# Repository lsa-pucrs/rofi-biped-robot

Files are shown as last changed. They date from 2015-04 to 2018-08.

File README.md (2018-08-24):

# rofi-biped-robot
Unoficial repository to Rofi biped robot (http://www.projectbiped.com/prototypes/rofi)

<p align="center">
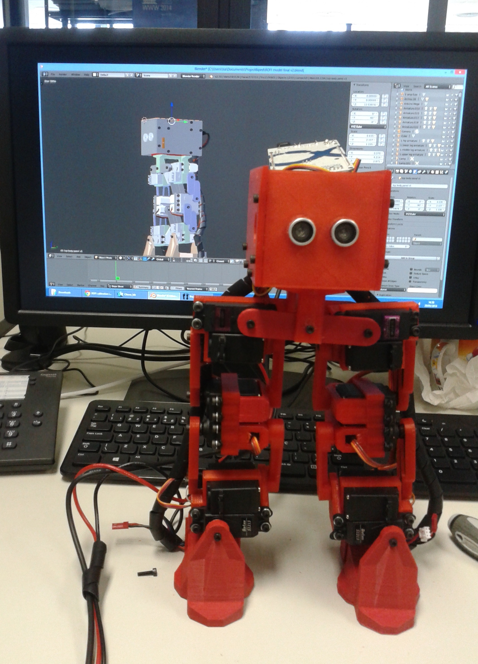
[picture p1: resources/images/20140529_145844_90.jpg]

</P>

####TO-DO_List:####
- [ ] Criar "abraçadeiras" para os servos, para melhorar a estrutura das pernas
- [ ] Manual de ultilização

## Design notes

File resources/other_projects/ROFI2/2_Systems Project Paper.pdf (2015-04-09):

1 | P a g e

# Android Controlled Based Interface

### Objective

- Fix Foba
- Build Rofi (Fifth Generation Robot)
- Develop, Build, and Implement a Dynamic Balanced Biped Robot

### Table of Contents

### Android Controlled Based Interface Design

### Embedded Systems

Engineers design systems. A system can be characterized by a box with an input and
output. Typically the engineer is tasked to design the box with a given set of inputs and a desired output.
- When a controller “the brain” is part of the design solution, the design is known as an Embedded System.
- The controller may be implemented using an ASIC (Application Integrated Circuit), FPGA (Field Programmable Gate Array) or in most cases a Microcontroller.
- For a microcontroller based design, the input device is by definition a Sensor, while the output device is known as an Actuator.
In this document we look at the Android based system design used by our rovers. It is hoped that by looking at this specific example you will be able to apply the lessons learned to the design of the Andriod based systems.

### Biped Android Based System Design

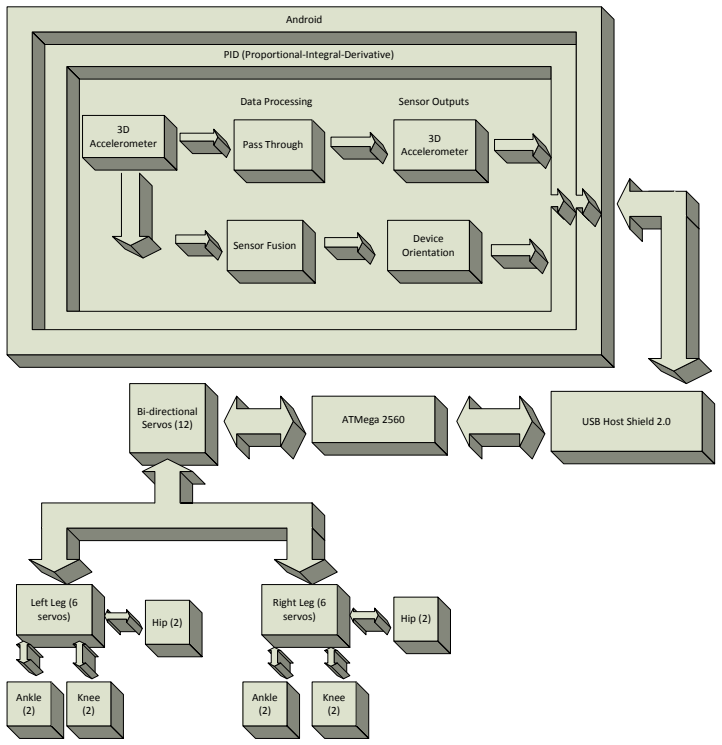
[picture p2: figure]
Sensor Fusion; 3D Accelerometer; Device Orientation; Pass Through; Android; Hip (2); Knee; (2) Ankle (2)

Data Processing | Sensor Outputs PID (Proportional-Integral-Derivative) 3D Accelerometer
ATMega 2560 | USB Host Shield 2.0 Bi-directional Servos (12)
Left Leg (6 servos) | Right Leg (6 servos) Ankle (2) | Knee

Figure 1.1 Biped Android Based System

The figure above illustrates our biped robot design from a generic capabilities perspective. At the heart of our Android we have the Android Sensor Manager.

### The ATMega2560 is built into an Arduino motherboard

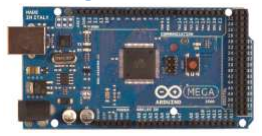
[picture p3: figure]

The Arduino Mega 2560 is a microcontroller board based on the ATmega2560 (datasheet). It has 54 digital input/output pins (of which 14 can be used as PWM outputs), 16 analog inputs, 4 UARTs (hardware serial ports), a 16 MHz crystal oscillator, a USB connection, a power jack, an ICSP header, and a reset button. It contains everything needed to support the microcontroller; simply connect it to a computer with a USB cable or power it with a AC-to-DC adapter or battery to get started. The Mega is compatible with most shields designed for the Arduino Duemilanove or Diecimila.

Important Characteristics
- Microcontroller ATmega2560
- Operating Voltage 5V
- Input Voltage (recommended) 7-12V
- Input Voltage (limits) 6-20V
- Digital I/O Pins 54 (of which 14 provide PWM output)
- Analog Input Pins 16
- DC Current per I/O Pin 40 mA
- DC Current for 3.3V Pin 50 mA
- Flash Memory 256 KB of which 8 KB used by bootloader
- SRAM 8 KB
- EEPROM 4 KB
- Clock Speed 16 MHz

### USB Host Shield 2.0 for Arduino

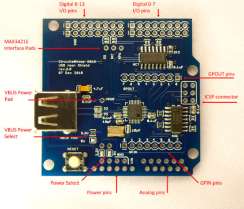
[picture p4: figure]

The figure above shows the USB Host Shield 2.0 for the Arduino. This host shield is compatible with a greater range of Arduinos, such as the Arduino UNO, Arduino Duemilanove, the big Mega and Mega 2560. SPI re-wiring and code modifications are not necessary, all you do is just solder included stackable connectors (2×3 ICSP connector’s female side should be facing down). This shield will work with standard (dual 5/3.3V) and 3.3V-only (for example, Arduino Pro) boards. Arduino clones with standard connector layout, including ICSP connector, should work, however only BlackWidow has been tested so far.

Devices that support the shield
- HID devices, such as keyboards, mice, joysticks, etc.
- USB to serial converters – FTDI, PL-2303, ACM, as well as certain cell phones and GPS receivers
- ADK-capable Android phones and tables
- Digital cameras – Canon EOS, Powershot, Nikon DSLRs and P&S, as well as generic PTP

### Interface Capabilities of our Integrated System

### Analog

Arduino | ATMega2560 | To Call Pin

USB Host
Shield | Servos

IR
Sensors
PIN 0 | PIN 97 | PF0 (ADC0)
PIN 1 | PIN 96 | PF1 (ADC1)
PIN 2 | PIN 95 | PF2 (ADC2)
PIN 3 | PIN 94 | PF3 (ADC3)
PIN 4 | PIN 93 | PF4 (ADC4/TCK)
PIN 5 | PIN 92 | PF5 (ADC5/TMS) | | Data Signal
PIN 6 | PIN 91 | PF6 (ADC6/TD0)
PIN 7 | PIN 90 | PF7 (ADC7/TDI)
PIN 8 | PIN 89 | PK0 (ADC8/PCINT16)
PIN 9 | PIN 88 | PK1 (ADC9/PCINT17) | INT

PIN 10 | PIN 87 | PK2 (ADC10/PCINT18) | SS
PIN 11 | PIN 86 | PK3 (ADC11/PCINT19)
PIN 12 | PIN 85 | PK4 (ADC12/PCINT20)
PIN 13 | PIN 84 | PK5 (ADC13/PCINT21)
PIN 14 | PIN 83 | PK6 (ADC14/PCINT22)
PIN 15 | PIN 82 | PK7 (ADC15/PCINT23)

### Digital

Arduino ATMega2560 To Call Pin

USB Host
Shield | Servos

IR
Sensors
PIN 13 | PIN 26 | PB7 (OC0A/OC1C/PCINT7)
PIN 12 | PIN 25 | PB6 (OC1B/PCINT6)
PIN 11 | PIN 24 | PB5 (OC1A/PCINT5)
PIN 10 | PIN 23 | PB4 (OC2A/PCINT4)
PIN 9 | PIN 18 | PH6 (OC2B)
PIN 8 | PIN 17 | PH5 (OC4C)
PIN 7 | PIN 16 | PH4 (OC4B)
PIN 6 | PIN 15 | PH3 (OC4A)
PIN 5 | PIN 5 | PE3 (OC3A/AIN1)
PIN 4 | PIN 1 | PG5 (OC0B)
PIN 3 | PIN 7 | PE5 (OC3C/INT5)
PIN 2 | PIN 6 | PE4 (OC3B/INT4)

### Communications

Arduino | ATMega2560 | To Call Pin | USB Host Shield | Servos

IR
Sensors
PIN 1 | PIN 3 | PE1 (TXD0)
PIN 0 | PIN 2 | PE0 (RXD0/PCINT8)
PIN 14 | PIN 64 | PJ1 (TXD3/PCINT10)
PIN 15 | PIN 63 | PJ0 (RXD3/PCINT9)
PIN 16 | PIN 13 | PH1 (TXD2)
PIN 17 | PIN 12 | PH0 (RXD2)
PIN 18 | PIN 46 | PDE (TXD1/INT3)
PIN 19 | PIN 45 | PD2 (RXD1/INT2)
PIN 20 | PIN 44 | PD1 (SDA/INT1)
PIN 21 | PIN 43 | PD0 (SCL/INT0)

### Digital

Digital
Arduino | ATMega2560 | To Call Pin | USB Host Shield | Servos | IR sensors
PIN 22 | PIN 78 | PA0 (AD0) | | Control Signal (Ankle)
PIN 23 | PIN 77 | PA1 (AD1)
PIN 24 | PIN 76 | PA2 (AD2) | | Control Signal (Lower Leg)
PIN 25 | PIN 75 | PA3 (AD3)
PIN 26 | PIN 74 | PA4 (AD4) | | Control Signal (Knee)
PIN 27 | PIN 73 | PA5 (AD5)
PIN 28 | PIN 72 | PA6 (AD6) | | Control Signal (Middle Leg)
PIN 29 | PIN 71 | PA7 (AD7)
PIN 30 | PIN 60 | PC7 (A15) | | Control Signal (Upper Leg)
PIN 31 | PIN 59 | PC6 (A14)
PIN 32 | PIN 58 | PC5 (A13) | | Control Signal (Hip)
PIN 33 | PIN 57 | PC4 (A12)
PIN 34 | PIN 56 | PC3 (A11)
PIN 35 | PIN 55 | PC2 (A10)
PIN 36 | PIN 54 | PC1 (A9)
PIN 37 | PIN 53 | PC0 (A8)
PIN 38 | PIN 50 | PD7 (T0)
PIN 39 | PIN 70 | PG2 (ALE)
PIN 40 | PIN 52 | PG1 (/RD) | | Control Signal (Ankle)
PIN 41 | PIN 51 | PG0 (/WR)
PIN 42 | PIN 42 | PL7 | | Control Signal (Lower Leg)
PIN 43 | PIN 41 | PL6
PIN 44 | PIN 40 | PL5 (OC5C) | | Control Signal (Knee)
PIN 45 | PIN 39 | PL4 (OC5B)
PIN 46 | PIN 38 | PL3 (OC5A) | | Control Signal (Middle Leg)
PIN 47 | PIN 37 | PL2 (T5)
PIN 48 | PIN 36 | PL1 (ICP5) | | Control Signal (Upper Leg)
PIN 49 | PIN 35 | PL0 (ICP4)
PIN 50 | PIN 22 | PB3 (MISO/PCINT3) | Connected via ICSP (MISO) | Control Signal (Hip)
PIN 51 | PIN 21 | PB2 (MOSI/PCINT2) | Connected via ICSP (MOSI)
PIN 52 | PIN 20 | PB1 (SCK/PCINT1) | Connected via ICSP (SCK)
PIN 53 | PIN 19 | PB0 (/SS/PCINT0)
GND | | | GND | GND | GND
AREF
5V PIN | | | PWR | PWR | PWR
RESET | | | RST

### ATmega2560 Pin Configuration(TQFP –pinout)

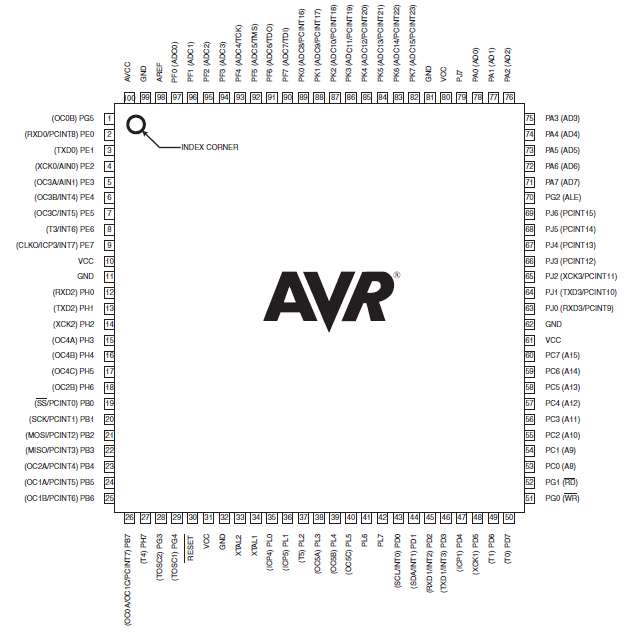
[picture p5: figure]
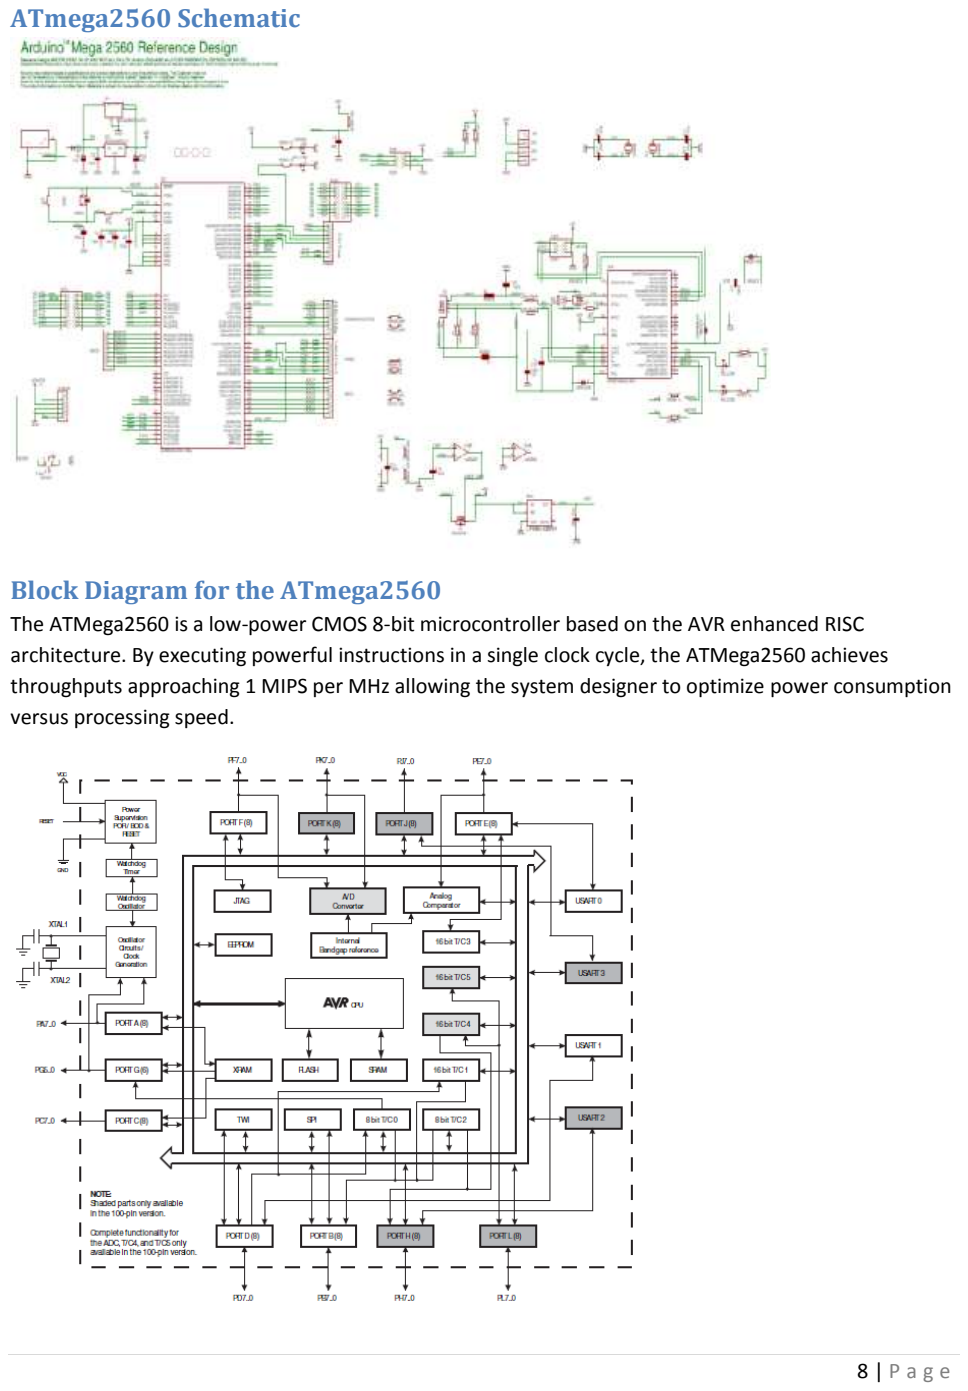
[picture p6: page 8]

### ATmega2560 Schematic

### Block Diagram for the ATmega2560

The ATMega2560 is a low-power CMOS 8-bit microcontroller based on the AVR enhanced RISC architecture. By executing powerful instructions in a single clock cycle, the ATMega2560 achieves throughputs approaching 1 MIPS per MHz allowing the system designer to optimize power consumption versus processing speed.

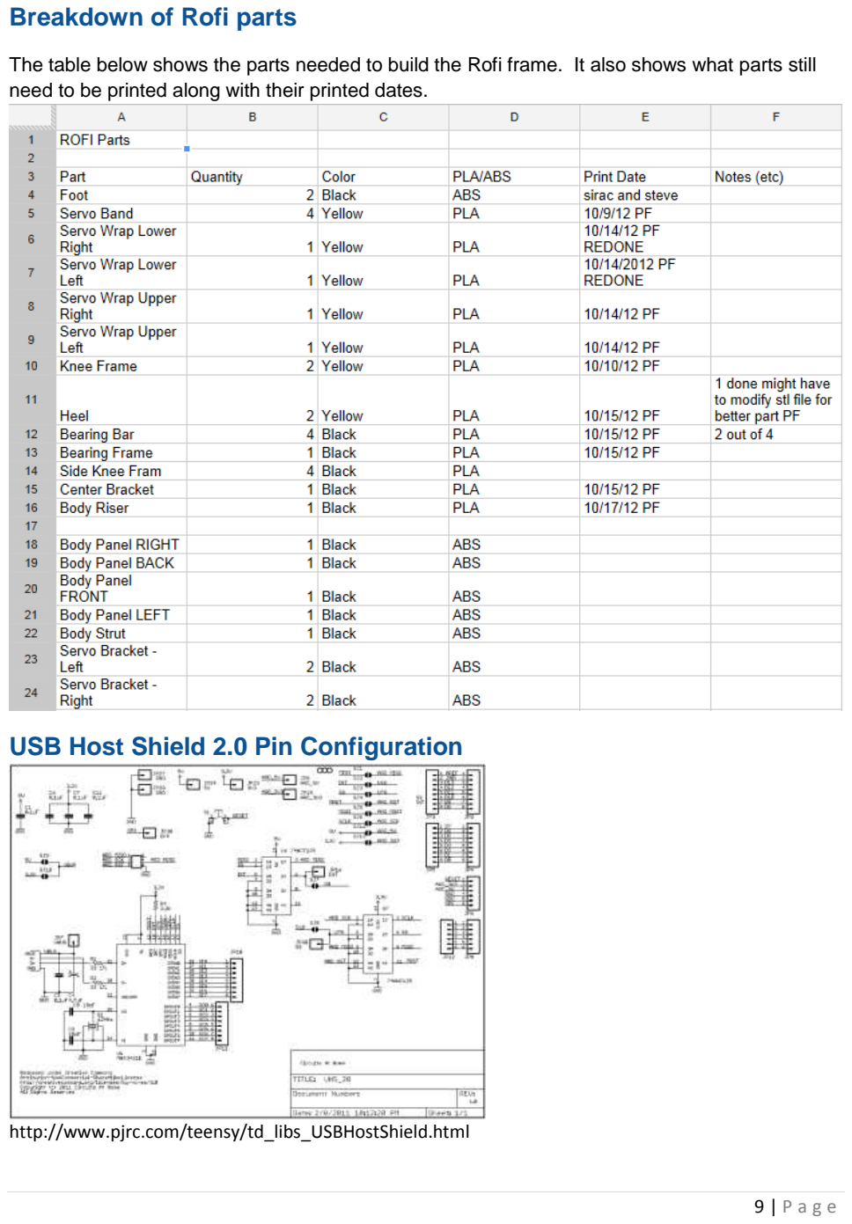
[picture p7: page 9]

### Breakdown of Rofi parts

The table below shows the parts needed to build the Rofi frame. It also shows what parts still need to be printed along with their printed dates.

### USB Host Shield 2.0 Pin Configuration

http://www.pjrc.com/teensy/td_libs_USBHostShield.html

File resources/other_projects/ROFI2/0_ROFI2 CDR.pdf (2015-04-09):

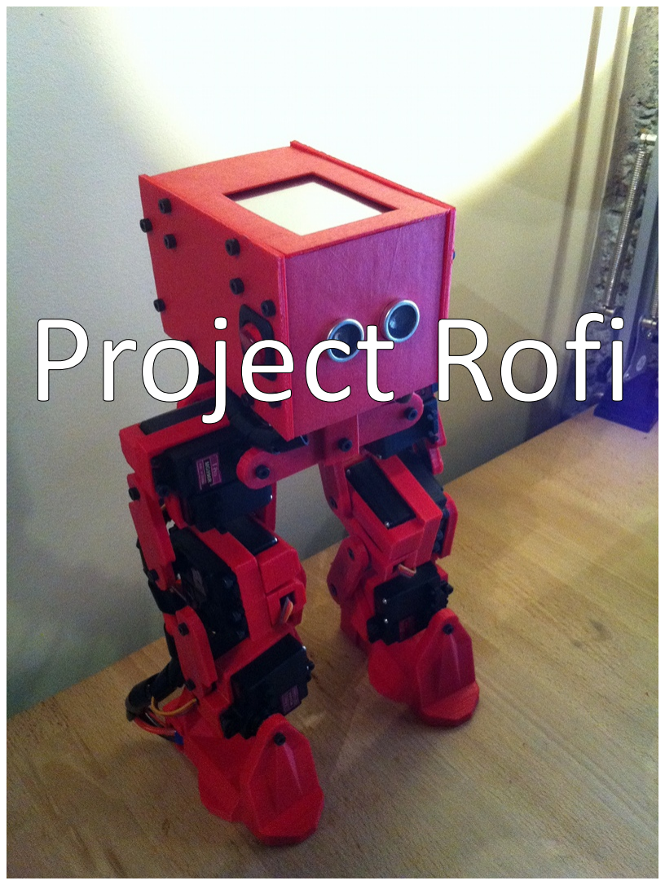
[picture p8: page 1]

### Research

- Project Biped by Jonathan Dowdall
– Fobo and Foba : static balanced
– Rofi: static but with accelerometer feedback to smooth walking
– http://www.projectbiped.com

## Rofi vs Fobo

| FoBo | Rofi
Static/Dynamic | Static | Partially Dynamic
FeedBack | None | Accelerometer
“Brain” | Arduino Uno | Android
Degrees of Freedom | 8 | 12
Sensors | Ultrasonic Range | Ultrasonic Range, Accelerometer (Android)
Batteries | 1 at center | 2, one at each foot
Plastic | 193cc, 206g (about 1/5 spool) | ABS plastic 1.75mm, 1kg
Build Time | 18 hours: 16 hours printing + 2 hours assembly | 30 hours: 25 hours printing + 5 hours assembly
Size | 9.5cm x 15.25cm x 24cm (4.5” x 6” x 9.5”) | 17.75cm x 11.45cm x 30.5cm (7” x 4.5” x 12”)

## RoFi

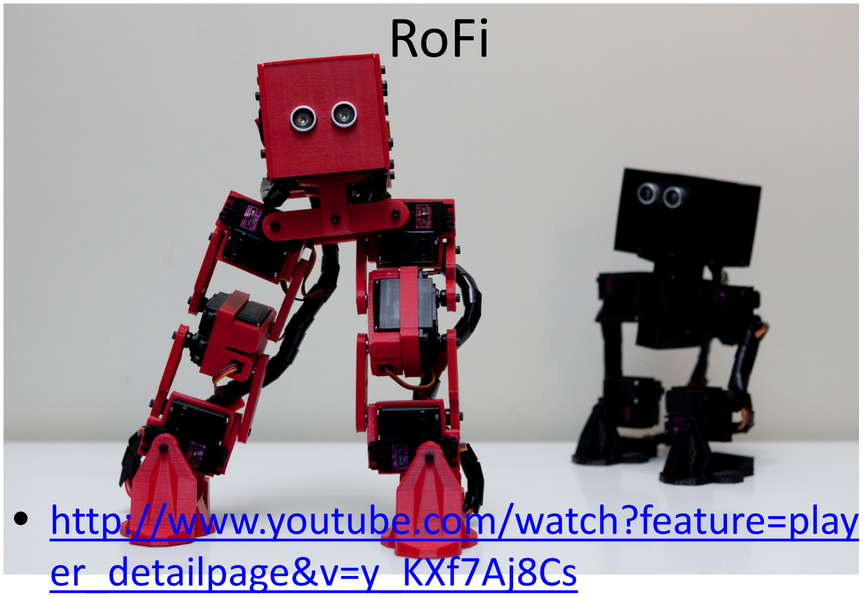
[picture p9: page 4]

- http://www.youtube.com/watch?feature=player_detailpage&v=y_KXf7Aj8Cs (http://www.youtube.com/watch?feature=player_detailpage&v=y_KXf7Aj8Cs)

### DareL-Next Generation Biped Robot

- Dynamic Android Robot, Engineered in Long beach
- Take elements from RoFi and improve upon them to build dynamic balanced walking robot.

## Requirements

- Complete and implement Rofi according to Jonathon Dowdall’s specifications.
- Design and Implement DareL, creating a fully dynamic biped robot

## Block Diagram Level 2

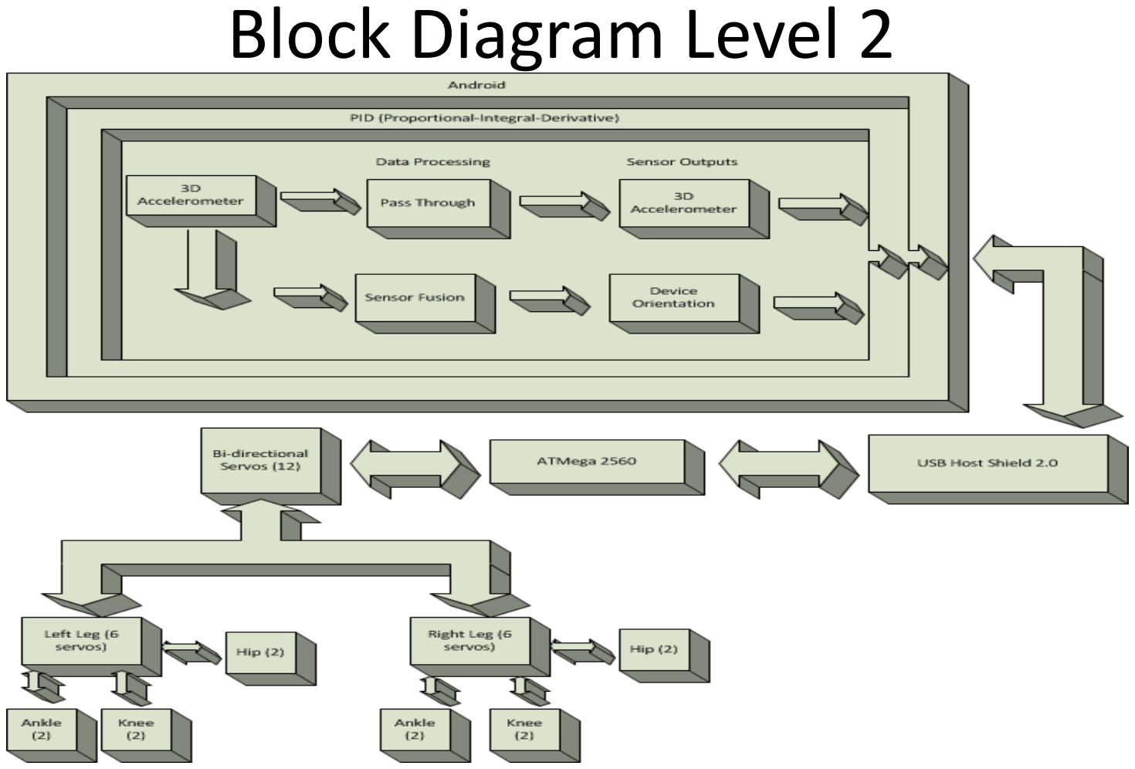
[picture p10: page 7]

### Interface Capabilities of our Integrated System

### Interface Capabilities of our Integrated System (Cont.)

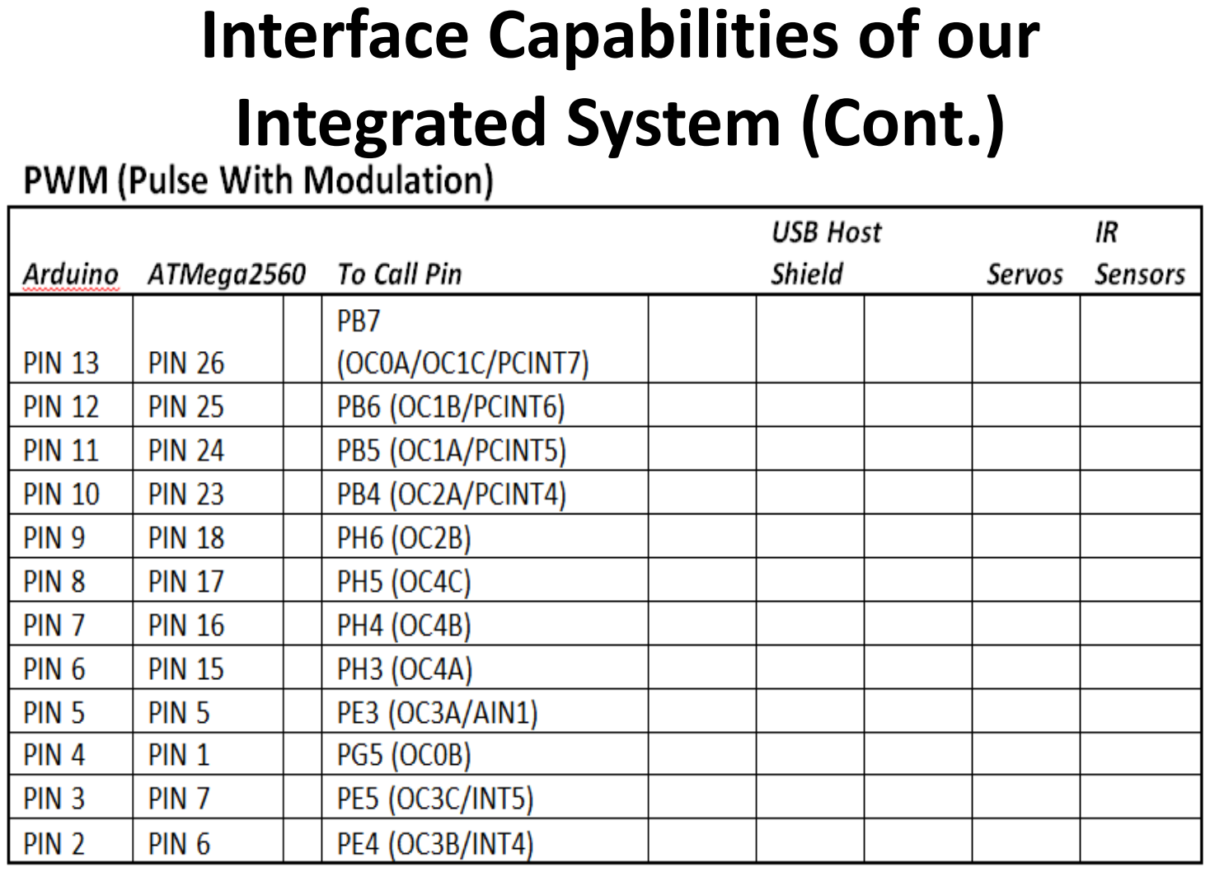
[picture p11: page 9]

### Interface Capabilities of our Integrated System (Cont.)

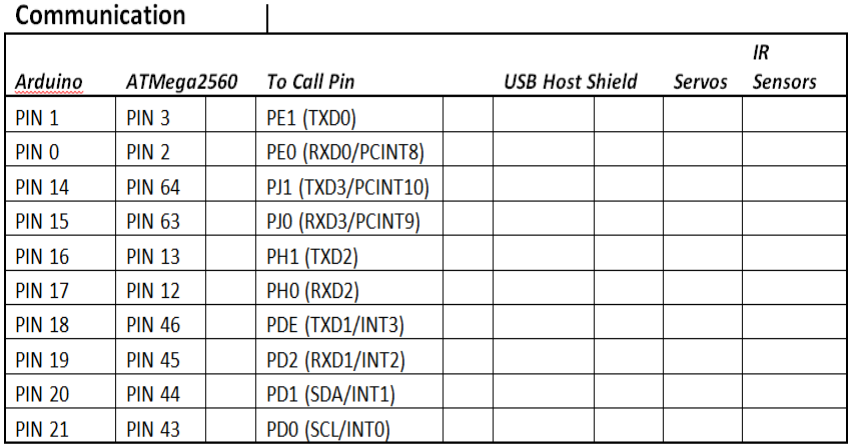
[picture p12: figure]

### Interface Capabilities of our Integrated System (Cont.)

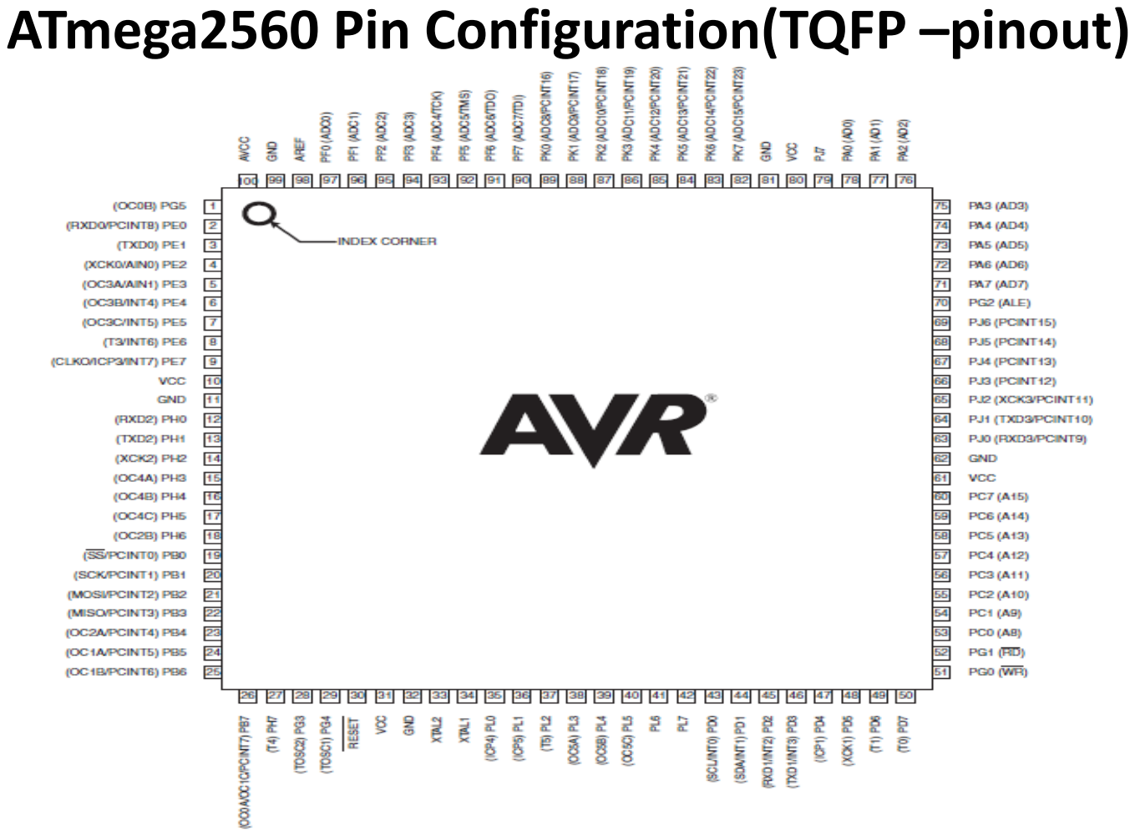
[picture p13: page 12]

ATmega2560 Pin Configuration(TQFP –pinout)

## ATmega2560 Schematic

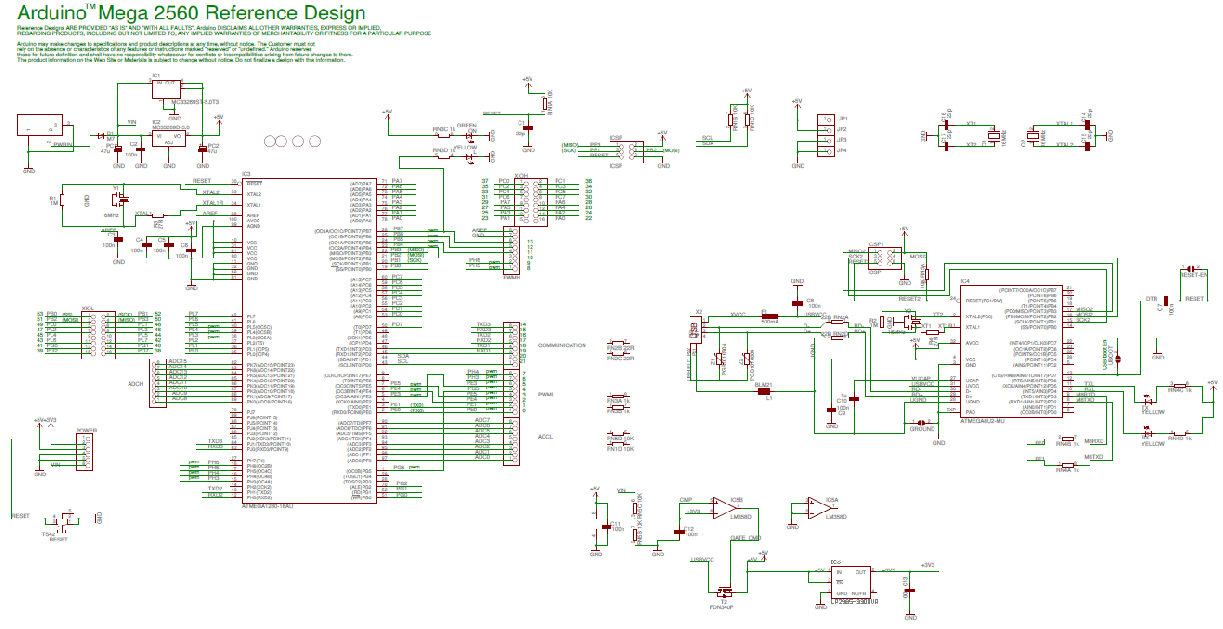
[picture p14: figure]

### Block Diagram for the ATmega2560

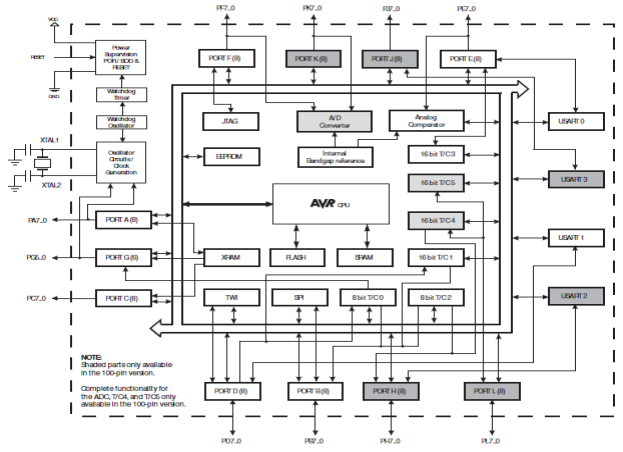
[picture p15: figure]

### USB Host Shield 2.0 Pin Configuration

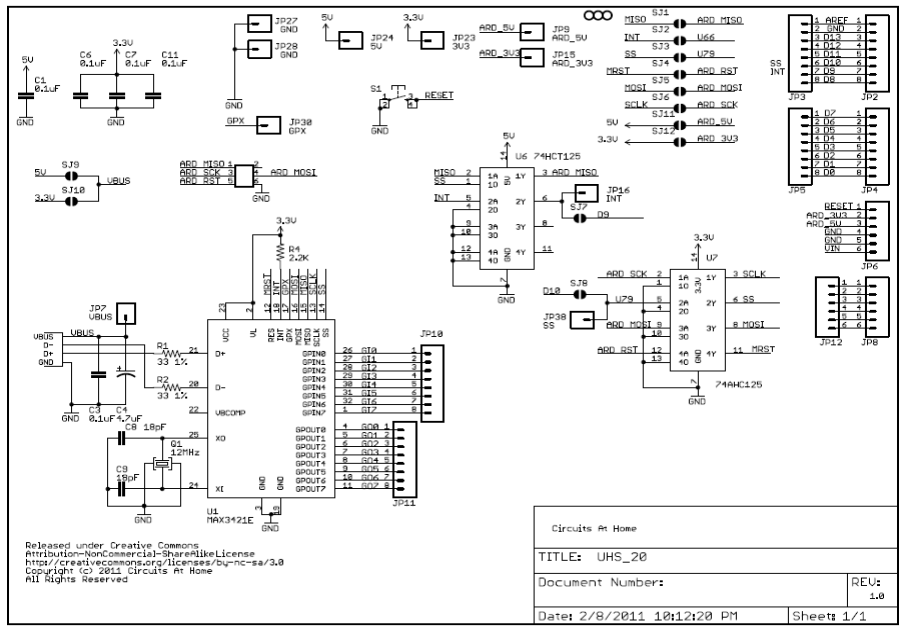
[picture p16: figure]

### Software Requirements-Rofi and DareL

Top-Top Level
- Establish bi-directional connection between Arduino and Android
- Program Android application that sends commands to move servos with Accelerometer and Gyro feedback.

## Hardware + Software

- Arduino Mega 2560
- USB Host Shield
- Archos Android Tablet
- USB Micro B to USB A
cable
- Arduino (C++)
– Servo library
– Microbridge library
- Eclipse (Java)
– Microbridge library
– Android SDK

## How It Works

- Create a server that listens to a port on the Android device via TCP (Programmed in Java)
- Arduino client connects to the port via TCP (Programmed in C++)
- Android Debug Bridge forwards TCP request connecting Arduino & Android

### Current Status of Android/Arduino Interface

- Android Application
– Communication with
Arduino via microbridge
success
– Accelerometer values
successfully accessed in
Android

## To Do

- Send Arduino gyro values to Android
- Program sensor filter with Accelerometer & Gyro in Java
- Program PID controller with sensor feedback in Java
- Correlate servo movement with PID output and send commands to Arduino

## Sensors-Gyroscope

- A gyroscope measures angular velocity, through integration we can get angle.
- The Gyroscope is accurate from the start but over time suffers from the drift effect

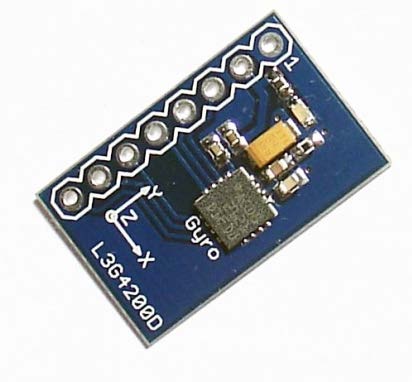
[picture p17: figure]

## Complementary Filter

- Through using the complementary filter, we plan on mixing, combining, and then estimating the data received from the Gyroscope and Accelerometer
- A complementary filter will compensate for the gyroscope drift effect and the accelerometer vibration error giving an accurate reading.
- It is a simplified version of the Kalman filter

## Example

- Red - accelerometer
- Green - Gyro
- Blue - Kalman filter
- Black - complementary filter
- Yellow - the second order complementary filter

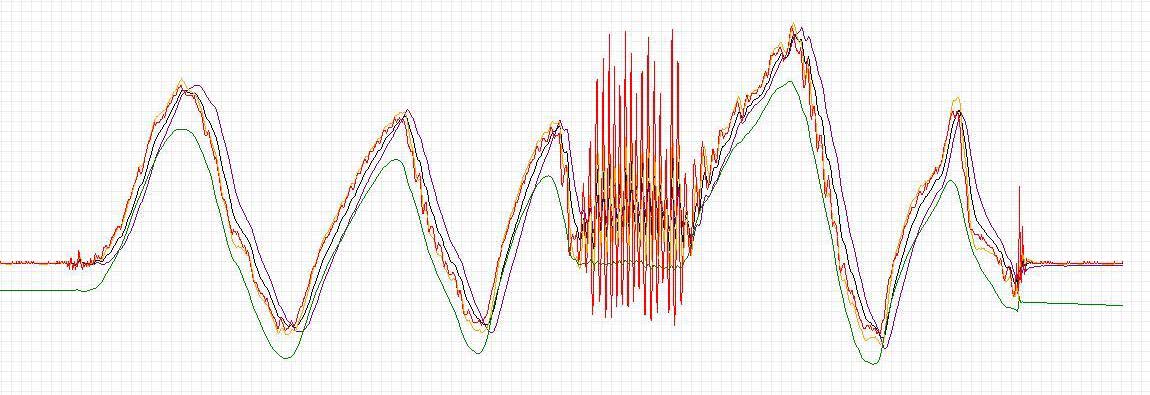
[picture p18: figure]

## Sensors-IR Ranger

- We plan to replace the ultrasonic sensor with an IR ranger for DareL, possibly Rofi
- Will improve accuracy over ultrasonic sensor by reducing the “field of view”

## References

- “ A Comparison of Complementary and Kalman Filtering” by WALTER T. HIGGINS, JR.
- http://www.ocf.berkeley.edu/~tmtong/kalman.php
- http://web.mit.edu/scolton/www/filter.pdf
- http://robottini.altervista.org/kalman-filter-vs-complementary-filter (http://robottini.altervista.org/kalman-filter-vs-complementary-filter)
- Sensors Powerpoint found in EE 444 reference page by Professor Hill

DareL
Next Generation 3d Modeling

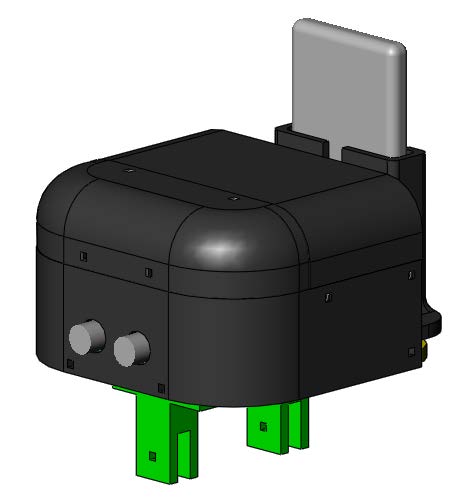
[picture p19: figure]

## Objectives For New Design:

– Main objective: move toward Dynamic Balance
- Raise center of gravity by moving the batteries out of the feet
- Re-design the foot
– To address lack of battery
– Narrower foot-print (instability)
– "Organic Curves“
– Secondary Objective: Incorporate internal phone sensors
- Re-design "Head"
– Re-orient phone to take advantage of back camera (if available)
– Devise mount system to adapt to size of available phone (upgrade capable) – Make room for Batteries, Ultrasonic/IR sensor, Gyro (if available)
– "Organic Curves"

## Execution of Objectives

- Parts List:
– Uniform Foot
– Head Bottom
– Phone Bracket Left
– Phone Bracket Right
– Head Sides
– Head Top
– Head Dome
+ Body Riser from Original ROFI

## Uniform Foot

- Same model for both
left and right
- Thicker walls around
bearing holes
- Narrower Footprint
- “Organic Curves”

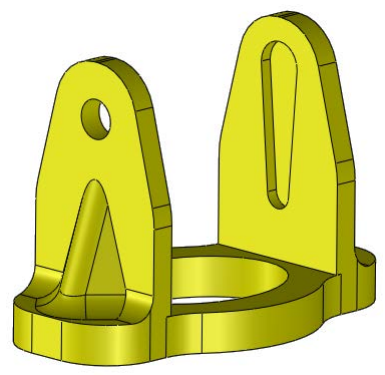
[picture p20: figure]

## New Head

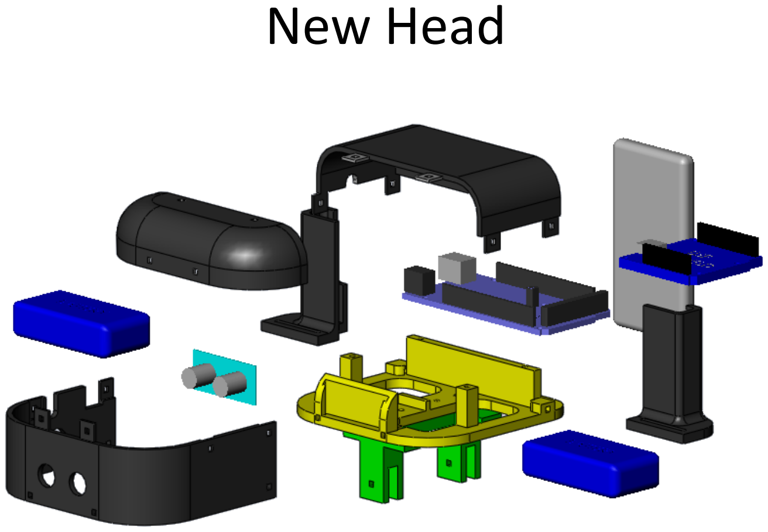
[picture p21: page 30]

## Head Bottom

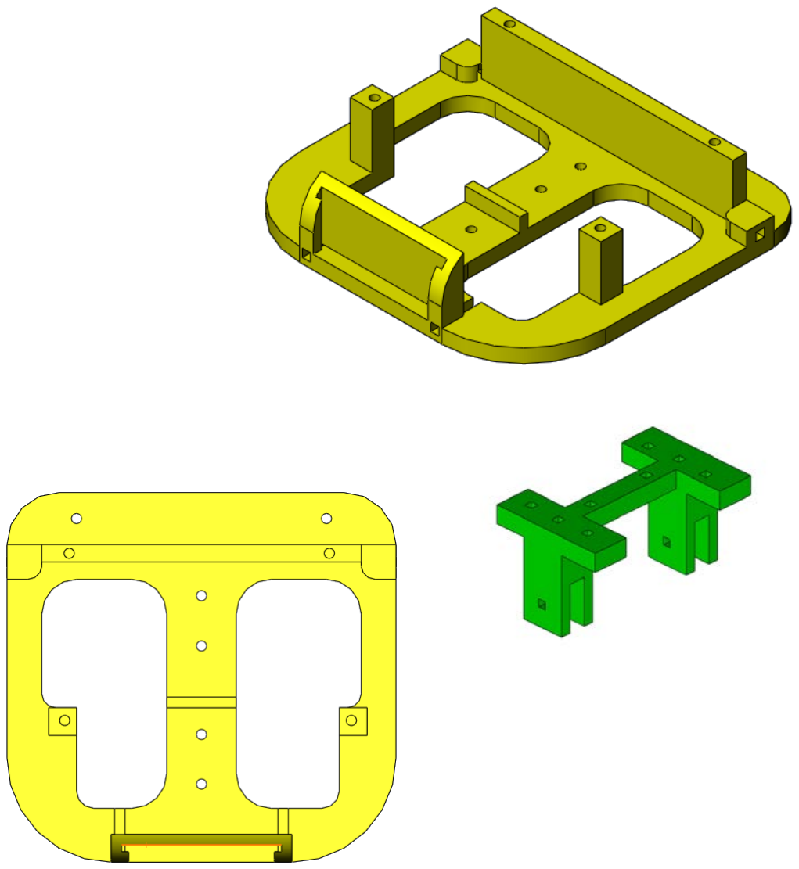
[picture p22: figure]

- Attaches to Original
ROFI “Body Riser”
- Arduino Mega Mounts
- Battery body stops
- Slot mount for Ultra
Sonic Range Finder
- Sliding Phone Bracket
Mounts

## Sliding Phone Bracket

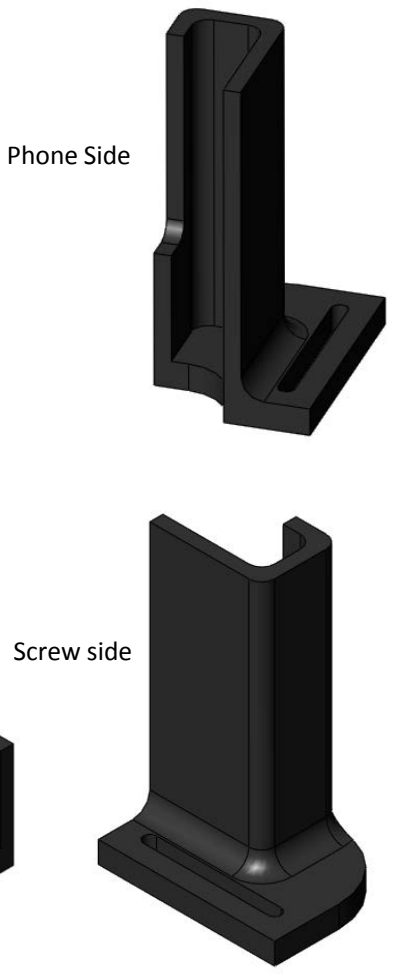
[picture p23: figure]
Phone Side; Screw side

- 2 Piece Bracket
- Adjusts from 48mm-105mm wide
- 60mm side walls support phone in a vertical orientation
- Non-slip inserts
- “Organic Curves”

## Head Sides

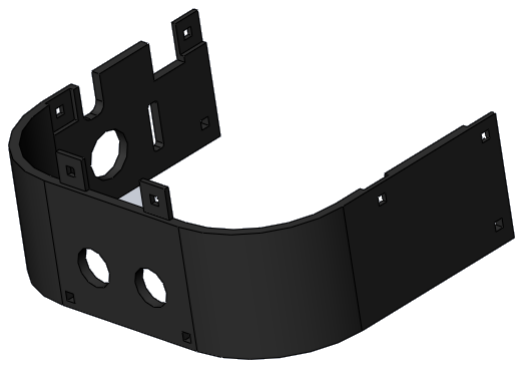
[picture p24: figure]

- Shell pieces attach with ‘tongue-and-groove’
plus screws
- Holes to accommodate
– Ultra Sonic RF “eyes”
– Servo Power Switch
– Servo Power Fuse
– Arduino Power
– Arduino USB

## Head Top

- Attaches to Head Sides
and Head Dome via
Tabs and screws
- Notch to accommodate
USB from USB shield

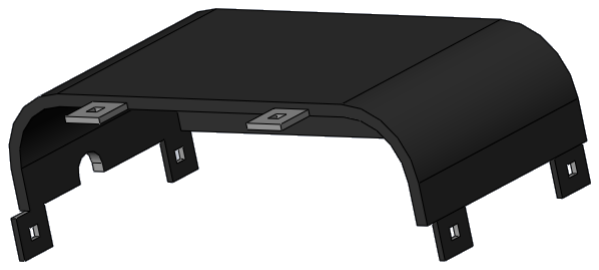
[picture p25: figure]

## Head Dome


- Attaches to Head Sides
and Head Top via
grooves and screws

Under side

Top side

## Looking Forward


- Phone with Back or Front Camera
- Phone with internal Gyro
- Use Phone camera for
Range Finder
- Entire assembly may be
rotated 180° for phone
with Front Camera

## Other Models


- Archos7 Phone
- Arduino Mega 2560
- Arduino USB Shield
- ROFI Battery
- Ultrasonic RF

## Control Issues

- Implement then improve on PID controller.
- Learn Solidworks to model the robot, bypassing the need for messy mathematical computations.
- Look into feasibility of redesigning knee joint to a more realistic model.
- Model with inverted pendulum approach.

## Schedule (Level 1)

## Schedule (Level 2)


## RoFi Cost-Parts


Main Support Issues

## Measures of Success

- Successful Rofi Operation
- Next Generation (DareL)
– Dynamic walking
– Walk up an incline
– Respond to impulse


## Conclusion

- Rofi is moving much slower than anticipated, but will be completed by end of semester.
- Unforeseen issues have limited the viability of implementing full functionality of DareL. In the event we are unable to complete DareL’s main objectives, our goal will be to provide resources and documentation to enable the success of next semester’s biped robot group.

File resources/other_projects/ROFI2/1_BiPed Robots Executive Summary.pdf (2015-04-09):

## Project Rofi

### Executive Summary

10/18/2012

Prioject Rofi’s goal is to design and implement a fully dynamic biped robot. The first mission is to complete Rofi (Fith Generation Robot), which was developed by Jonathon Dowdal. Rofi is a partially dynamic robot that uses the accelerometer in an android tablet as the feedback sensor. Project Rofi will build this robot, and then change some of the features to better utilize the android phone as well as add a medium range IR sensor and a gyro.

As mentioned before, Rofi is the next generation robot in a series of biped robots. Its predecessor, FOBA, was built by the last semester’s class and was a static machine. In order to fully understand the processes and differences between static and dynamic bipeds, FOBA must be restored to its proper working order. This task has been completed.

In order to keep costs down, FOBA was dismantled and scrapped for parts. This too has been completed. Every part has been ordered and received for Rofi, and the project is awaiting parts from the manufacturing team. Progress is slow, but is getting on track. The Maker Society has also been a valuable resource in attaining these goals. Project Rofi is scheduled to begin building Rofi on 10/18/2012 with the parts it has attained. Once the programs are posted, Rofi will be implemented.

The next generation biped, Darel (Dynamic Android Robot Engineering Long Beach), has a redesigned head, but will use the same legs as Rofi. This was done to keep the cost down, as well as to maintain the same basic walking frames. Furthermore, the feedback will be increased by using an external gyro along with the android’s accelerometer to increase accuracy. Preliminary designs allow for the use of a variety of phones. This will allow the user to be able to download the app and control Darel with any phone. This app will check for phones features to be available for use since not all androids have the same features. Other feature’s if schedule allows are implementing voice commands, wifi control, and using the android’s camera. The cost of Rofi will be $233.40 minus the costs for plastic. This will allocate around $20-$50 for any unexpected costs, but these should be kept to a minimum.

The success of Darel will be based on three tests. First, Darel will be fully dynamic meaning it will fall when the power is turned off. Second, Darel will be able to walk up an incline. Third, Darel will be able to respond to a slight impulse; Similar to being pushed. These are lofty goals and time will be short, but by keeping a motivated and enthusiastic group, Project Rofi will be able to attain these goals and produce an inexpensive dynamic biped robot.


Rofi

DareL

11/18 Sep 2012; Oct 2012; Nov 2012 9/16; Team Biped; Dec 2012 12/2; % Complete

Get FoBa working Order/Received Rofi Parts Print RoFi Parts Build RoFi Implement RoFi Improve Android “Brain” elements Print/Order Parts for Next Generation Build Next Generation Task Name | 10/19/2012 10/26/2012 10/16/2012 10/23/2012 9/17/2012 9/26/2012 10/8/2012 10/3/2012 11/1/2012 Start | 10/15/2012 10/18/2012 10/25/2012 11/22/2012 12/14/2012 10/31/2012 9/25/2012 11/5/2012 11/7/2012 Finish | Duration 14d 37d Design Next Generation RoFi Body Modifications 7 44d 8 7d 9d 4 5d 5 7d 6 7d 9 5d | 10% | 7d 9/25/2012 2 14d 3 11/4 11/11 11/25 1

10 | Implement Next Generation* | 11/8/2012 | 12/14/2012 | 27d | 0%

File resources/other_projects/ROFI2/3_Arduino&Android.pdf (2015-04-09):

# Arduino & Android

## A “How to” on interfacing these two devices

### Bryant Tram

1 | T r a m | 2 9 N o v e m b e r 2 0 1 2

## Contents

2 | T r a m | 2 9 N o v e m b e r 2 0 1 2

## 1 Overview

In this “how to” guide, I will show you the programs and steps needed to get the Arduino and the

Android phone to communicate with and interface together. First, you will be introduced to the

hardware and devices that will be use. Secondly, you will be shown the programs that are used

after the initial set up to initialize the board and android. Lastly, I will show you an example lab

showing the board and android working together.

## 2 Other Readings

### 1. Android Debug Bridge -

The Android Debug Bridge is command tool within the Android platform that allows for the

Android Device to be connected to other emulators or devices. This article will inform you on

how this tool works. It will also provide supported ADB commands and how to implement them.

http://developer.android.com/tools/help/adb.html

### 2. MicroBridge –

MicroBridge is the microcontroller’s version of Android Debug Bridge and it will allow

microcontrollers such as our Arduino Mega to interface with the Android via the USB shield.

This article is written by the author of the MicroBridge code and will explain how it works with

the Android and provide greater understanding of the code.

http://code.google.com/p/microbridge/

### 3. YouTube tutorial video series on how to build your own android app

http://www.youtube.com/course?list=ECB03EA9545DD188C3&feature=plcp


3 | T r a m | 2 9 N o v e m b e r 2 0 1 2

## 3 Hardware and Devices

Where to buy:
1. Arduino Mega 2560 – Figure 1 http://www.seeedstudio.com/depot/arduino-mega-2560-p-695.html?cPath=132_133
2. USB Host Shield – Figure 2
https://www.sparkfun.com/products/9947?
Or
http://www.circuitsathome.com/products-page/arduino-shields/usb-host-shield-2-0-for-arduino
3. Android 1.5+ device – ex. Archos - 28 Internet Tablet – Figure 3 http://www.newegg.com/Product/Product.aspx?Item=N82E16855501057
Figure 1

Figure 1. Arduino Mega 2560 (Arduino website)


4 | T r a m | 2 9 N o v e m b e r 2 0 1 2

Figure 2

Figure 2. USB Host Shield (Circuitsathome.com)

Figure 3

Figure 3. Archos -28 Internet Tablet (Amazon)

5 | T r a m | 2 9 N o v e m b e r 2 0 1 2

## 4 Programs Download

Each program is free to download and can be found at the links provided.

1. Arduino 1.0.1 software
http://arduino.cc/en/Main/Software
2. Java Eclipse
http://www.eclipse.org/downloads/

## 5 Other Downloads

The Arduino IDE requires these libraries to be added in order to implement the lab.

1. USB Host Shield library http://code.google.com/p/microbridge/downloads/detail?name=MicroBridge-Arduino.zip&can=2&q= (http://code.google.com/p/microbridge/downloads/detail?name=MicroBridge-Arduino.zip&can=2&q=)
2. MicroBridge Arduino Library http://code.google.com/p/microbridge/downloads/detail?name=MicroBridge-Arduino.zip&can=2&q= (http://code.google.com/p/microbridge/downloads/detail?name=MicroBridge-Arduino.zip&can=2&q=)
3. Servo Control demo App – An example of another lab that could be done after this one. http://code.google.com/p/microbridge/downloads/detail?name=ServoControl.zip&can=2&q=

6 | T r a m | 2 9 N o v e m b e r 2 0 1 2

## 6 Setting up the Arduino Program

### 6.1 Step 1: Download and Extract the Arduino folder

Download and Extract the files in the arduino-1.0.1.zip files included in this folder. The extracted folder should include the following files.

## FOLDERS

### 1. drivers 2. examples 3. hardware 4. java 5. lib 6. libraries 7. reference 8. tools

## FILES

### 1. arduino.exe 2. cygiconv-2.dll 3. cygwin1.dll 4. libusb0.dll 5. revisions.txt 6. rxtxSerial.dll

### 6.2 Step 2: Download and place the Microbridge library

### - Download and Extract the files in the MicroBridge-Arduino.zip files

included in this folder.
- This folder should contain another folder label Adb.

### - Now take this folder and drop it into the Arduino folder “6. Libraries”

### 6.3 Step 3: Modifying the Library (conditional)

### If you are using the Arduino Mega 2560 with the USB shield from:

http://www.circuitsathome.com/products-page/arduino-shields/usb-host-shield-2-0-for-arduino

### Then go to the Adb Folder and Right click “edit” on the file max3421e.h Then on the line 67 & 80 change the following:

#define MAX_SS(x) digitalWrite(SS, x)

into
#define MAX_SS(x) digitalWrite(PIN_MAX_SS, x)

### If you are using the USB host shield from sparkfun:

https://www.sparkfun.com/products/9947?

### Then do not modify the Library file We have not tested this library on this USB shield from sparkfun but Jonathon

Dowdall, creator of RoFi, has got it to work on it as is.


7 | T r a m | 2 9 N o v e m b e r 2 0 1 2

## 7 Install Java / Eclipse and set up the Android SDK

### 7.1 Step 1: Download Eclipse & Install Eclipse

### Download Eclipse IDE for Java Developers at the following website:

http://www.eclipse.org/downloads/

### - *Make sure you download the correct version for whatever JAVA version you are using* Either the 64-bit or 32-bit - If not sure then go to control panel and click on programs to see which one are your system is running

### 7.2 Step 2: Install Android SDK

Download and install the Android SDK manager:

http://developer.android.com/sdk/index.html

After the Manager is installed your screen should look like Figure 4. Figure 4

Figure 4. Screenshot of the Android SDK Manager

8 | T r a m | 2 9 N o v e m b e r 2 0 1 2

Now install the SDK you will be using which are the one that are currently checked.

- Android 2.3.3
- Android 2.2
- Android 2.1

After clicking install, it will take some time for your computer to download and install. Also note where the PATH of the SDK is installed

### 7.3 Step 3: Install ADT plugin for Eclipse

1. Start Eclipse, then select Help > Install New Software.
2. Click Add, in the top-right corner. Refer to Figure 5
3. Type in “ADT Plugin” for name and https://dl-ssl.google.com/android/eclipse/ for location
4. Then check on Developer Tools and click on next and install: Refer to Figure 7
If you get a security warning saying that the authenticity or validity of the software can't be established, click OK
5. Restart Eclipse
6. Once Eclipse restarts, in the "Welcome to Android Development" window that appears, select Use existing SDKs
7. Now you will be asked the location of the SDK you recently downloaded in STEP 7.2. So copy and paste the location given in 7.2 and paste. Then click Next.

At this point if you have ran into any errors then you have successfully install and configure Eclipse to develop Android Apps.


9 | T r a m | 2 9 N o v e m b e r 2 0 1 2

Figure 5

Figure 5. The window that pops up after clicking Install New Software


10 | T r a m | 2 9 N o v e m b e r 2 0 1 2

Figure 6

Figure 6. Screen for step 3

Figure 7

Figure 7. Screen for step 4


11 | T r a m | 2 9 N o v e m b e r 2 0 1 2

## 8 Compiling the apk and uploading the Adb code

### 8.1 Step 1: Starting a new eclipse project

1. Start Eclipse, then select File > New > Project
2. Select Android Application Project then click Next Figure 8

Figure 8. New Project Window

3. Now we name our project/app name
(Typing in the application name box will adjust the rest of the names)


12 | T r a m | 2 9 N o v e m b e r 2 0 1 2
4. Change the Build SDK to whichever android platform your device is working on. For the Archos, use API 7. Refer to Figure 9
Figure 9

Figure 9. Screen of New Android Application


13 | T r a m | 2 9 N o v e m b e r 2 0 1 2
5. This step is where you can edit the icon of the app (optional) For now we will just skip this step and just click next
Figure 10

Figure 10. Screenshot of the Icon edit window

6. In the Create Activity screen, just click next since we want to customize our app from scratch.
7. Now we click finish and it will take you to the app editor / workspace. Refer to figure 11


14 | T r a m | 2 9 N o v e m b e r 2 0 1 2

Figure 11

Figure 11. This is what your workspace should look like


15 | T r a m | 2 9 N o v e m b e r 2 0 1 2

### 8.2 Step 2A: Setting up the application screen

1. This part is where you add buttons and such to the screen and it will be the layout in the android device. First you should make sure the screen size is correct for your device. In our case it is 2.7 QVG
Figure 12

Figure 12. Change the layout of the screen workspace into the format your Android device is in.

2. Now we place a button on the main screen by dragging and dropping it there. Refer to the red arrows if you don’t know where. Refer to Figure 13
3. Now we add the other values by clicking on the activity_main.xml tab at the bottom of the screen and just copy and paste this code right in. Refer to Figure 14
4. Now go to your MainActivity.java file and double click it to open up the file window. And copy and paste the code provided underneath your package file. Refer to Figure 15
5. Now just run and compile the project and it should produce an APK file inside the bin folder. We now just connect the android to your computer and drop the apk file into the device. Then just install it by clicking on the apk file while using the device.


16 | T r a m | 2 9 N o v e m b e r 2 0 1 2

Figure 13

Figure 13. Click and drag the button onto the screen Figure 14

Figure 14. The tab for the screen containing the code for the layout of the screen

17 | T r a m | 2 9 N o v e m b e r 2 0 1 2

Note that this code is the java code for the layout of app.
CODE for activity_main.xml:
<RelativeLayout
xmlns:android="http://schemas.android.com/apk/res/android"xmlns:tools="http://schemas.android.com/tools"android:layout_width="fill_parent"android:layout_height="fill_parent" >

<TextView
android:id="@+id/accelerometerX" android:layout_width="wrap_content" android:layout_height="wrap_content" android:layout_alignParentLeft="true" android:layout_alignParentTop="true" android:layout_marginLeft="70dp" android:layout_marginTop="54dp" android:text="X:" />

<TextView
android:id="@+id/accelerometerY" android:layout_width="wrap_content" android:layout_height="wrap_content" android:layout_alignLeft="@+id/accelerometerX" android:layout_below="@+id/accelerometerX" android:layout_marginTop="30dp" android:text="Y:" />

<TextView
android:id="@+id/accelerometerZ" android:layout_width="wrap_content" android:layout_height="wrap_content" android:layout_alignLeft="@+id/accelerometerY" android:layout_below="@+id/accelerometerY" android:layout_marginTop="30dp" android:text="Z:" />

<Button
android:id="@+id/button1"
android:layout_width="wrap_content" android:layout_height="wrap_content" android:layout_alignLeft="@+id/accelerometerZ" android:layout_below="@+id/accelerometerZ" android:layout_marginTop="37dp" android:onClick="toggleLed" android:text="Toggle LED" />

</RelativeLayout>


18 | T r a m | 2 9 N o v e m b e r 2 0 1 2

Figure 15

Figure 15. Where the main code of the program is located

Code for the Main Activity section: import java.io.IOException;

import org.microbridge.server.Server;

import android.app.Activity;
import android.content.Context;
import android.content.res.Configuration; import android.hardware.Sensor;
import android.hardware.SensorEvent; import android.hardware.SensorEventListener; import android.hardware.SensorManager; import android.os.Bundle;
import android.util.Log;
import android.view.Menu;
import android.view.View;
import android.widget.TextView;

public class MainActivity extends Activity implements SensorEventListener {

sensorManager =; accelerometer =; SensorManager.SENSOR_DELAY_NORMAL);; try {; server = new Server(4567); server.start(); } catch (IOException e) {; System.exit(-1);

19 | T r a m | 2 9 N o v e m b e r 2 0 1 2

private SensorManager sensorManager; private Sensor accelerometer;

private TextView accX;
private TextView accY;
private TextView accZ;

Server server = null;

@Override
public void onCreate(Bundle savedInstanceState) { super.onCreate(savedInstanceState); setContentView(R.layout.activity_main);

accX = (TextView)findViewById(R.id.accelerometerX); accY = (TextView)findViewById(R.id.accelerometerY); accZ = (TextView)findViewById(R.id.accelerometerZ);

(SensorManager)getSystemService(Context.SENSOR_SERVICE);

sensorManager.getDefaultSensor(Sensor.TYPE_ACCELEROMETER); sensorManager.registerListener(this, accelerometer,

Log.e("microbridge", "Unable to start TCP server", e);

}

@Override
public boolean onCreateOptionsMenu(Menu menu) { getMenuInflater().inflate(R.menu.activity_main, menu); return true;
}

@Override
public void onConfigurationChanged(Configuration newConfig) { super.onConfigurationChanged(newConfig); }

@Override
protected void onResume() {
super.onResume();
sensorManager.registerListener(this, accelerometer, SensorManager.SENSOR_DELAY_NORMAL);

20 | T r a m | 2 9 N o v e m b e r 2 0 1 2

}

@Override
protected void onPause() { super.onPause();
sensorManager.unregisterListener(this);
}

public void onAccuracyChanged(Sensor arg0, int arg1) { // TODO Auto-generated method stub

}

public void onSensorChanged(SensorEvent event) { // TODO Auto-generated method stub
float x = event.values[0];
float y = event.values[1];
float z = event.values[2];

accX.setText("X: " + String.format("%.2f", x)); accY.setText("Y: " + String.format("%.2f", y)); accZ.setText("Z: " + String.format("%.2f", z));

try {
server.send(new byte[] { (byte)0, (byte)x, (byte)y, (byte)z });
} catch (IOException e) {
Log.e("microbridge", "problem sending TCP message", e);
}

}

public void toggleLed(View view) { try {
server.send(new byte[] { (byte)1 });
} catch (IOException e) {
Log.e("microbridge", "problem sending TCP message", e);
}
}
}

### 8.3 Step 2B: Compiling code if you have the Source code

1. If you have the source code folder which I included in the folder with this tutorial, then take these steps to compile the code. First Start Eclipse, then select File > New > Project
2. Now this time select Android Application Project from existing code then click Next


21 | T r a m | 2 9 N o v e m b e r 2 0 1 2

Figure 16

Figure 16. Screenshot of what to click when source code is provided
3. Now browse for where ever you extracted the Rofi.zip folder to and to check copy project to workspace as well. Then click finish.


22 | T r a m | 2 9 N o v e m b e r 2 0 1 2

Figure 17

Figure 17. Select the source code location

4. Everything should be ready to be compiled so from there just hit run and the file will be compiled.

### 8.4 Compile and upload the Arduino code

1. Now we will compile the Arduino code and upload it onto our board. Open up the arduino.exe and open the Android.ino file included in the folder.
2. Click verify / compile under the sketch tab.
3. Now just upload your code to your board under files.


23 | T r a m | 2 9 N o v e m b e r 2 0 1 2

## 9 Connecting the wires/ Expected results

1. At this point your Arduino should still be connected to your computer, you should leave it connected.
2. Now connect the micro USB cable from the Android to the USB shield.
3. Run the App which in this case is Rofi
4. Now you should see three values which is constantly changing according the way you hold the device and everytime you click the toggleLED button, you should see the led at pin 13 turn on and off.
Figure 18

Figure 18. What my setup looks like after everything is installed and uploaded.

24 | T r a m | 2 9 N o v e m b e r 2 0 1 2

## Appendix A Tips & Troubleshooting

- If an error pops up during runtime that MicroBridge server cannot start. Then check to make sure that android.permission.INTERNET is in the AndroidManifest.xml file. This is because MicroBridge requires internet APIs.
- If your Android application crashes when the orientation changes, then add android:configChanges="keyboardHidden|orientation" to the activity node in the AndroidManifest.xml file and add this method to your main activity file.

@Override
public void onConfigurationChanged(Configuration newConfig) { super.onConfigurationChanged(newConfig);
}

This mainly a bug in older Android versions 2.3 and below, but has been fixed in Android versions 3.0+.

## References and Websites

Great guide on installing the SDK http://www.talkandroid.com/guides/developer/android-sdk-install-guide/

Android Debug Bridge
http://developer.android.com/tools/help/adb.html

MicroBridge
http://code.google.com/p/microbridge/

Great YouTube tutorial videos on how to build your own android app http://www.youtube.com/course?list=ECB03EA9545DD188C3&feature=plcp

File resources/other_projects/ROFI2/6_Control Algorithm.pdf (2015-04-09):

# EE 400D

# Electrical Engineering Design Seminar and Project


# Control Algorithm Stable Walking of Biped Robots

# Isauro Ramirez

# November 27, 2012

Ramirez

## Table of Contents

## Abstract

This paper deals with the theory behind the control algorithm for the stability of walking biped robots. Many control algorithms have been implemented to perform stable walking without using any pre-computed trajectories. Controlling the direction of balance for biped walking robot such as ROFI would essentially imitate the human walking form. The goal of ROFI’s next generation robot is to maintain an upright torso while advancing one leg in front of the other in a continuous motion. When designing the control of the robot, the mechanical structure has to be analyzed carefully because of factors such as the number of degrees of freedom, weight of legs, and appropriate velocity and acceleration. By increasing the degrees of freedom, the robot becomes smoother but the complexity to control the robot increases as well. However, in order to fully develop a proper walking control algorithm, one has to consider the uneven and inclined floor. The current walking control techniques available that have been developed assume that the walking surface is perfectly flat with no inclination. Any slight unevenness of a floor can cause the robot to become unstable. In this paper, the author examines and suggests a control algorithm that has been developed by engineers from the research center Humanoid Robot Research Center stationed in South Korea. Also, the biped robot is modeled using the classical control model, the inverted pendulum.

## Introduction

In our senior design course, EE 400D, our group assembled a biped robot with 12 degrees of freedom. Many similar biped robots have been developed, such as the Honda’s humanoid robot Asimo. The goal of each robot is to have a stable control system so that the robot can perform a stable and reliable walking motion that resembles the human form. The currents robots available demonstrate an unnatural walking motion. The unnatural walking can be due to the weight of the robot. Understanding where to place the center of mass of the robot is important in establishing a robust system. Also, the number of degrees of freedom improve the steadiness and smoothness of the walking as well. As explained earlier, the complexity increases with the increase in degrees of freedom. Therefore, the control of a biped robot poses several challenging problems to designers. Most biped designs have a high center of mass which is supported by two feet. Many believe this is the essential reason why balancing and stabilizing a robot continues to create problems. Even after achieving an acceptable control system, several if not most robots appear to walk awkwardly with slow velocities. The walking control is performed on two levels: computation of the gait trajectories and local control along them. The overall stability or balancing should be considered on both levels [1]. On the first level, the synergy method and methods based on optimization are often used [7] [8]. By using the synergy method, most of the joint’s trajectories are created and the remaining trajectories are calculated relative to the stability of the robot. The second level controllers calculate pre-computed trajectories for the robot’s actuators. Being able to establish a coexisting relationship between the two levels should implement an acceptable human-like walking motion. If the dynamic balance can be maintained, dynamic walking is smoother and more active. Inertial forces must be controlled. If the inertial forces generated from the acceleration of the robot’s body are not controlled, the robot will fall down. By modeling the robot with a 3D application like Solidworks, the masses and torques can be calculated.

## Control Algorithm

1. Inverted Pendulum:
The inverted pendulum is a classical problem in dynamics and control theory and is widely used as a benchmark for testing control algorithms. The inverted pendulum is modeled using linear methods even though the system is essentially non-linear. The physical system consists of a cart, driven by a DC motor, and a pendulum attached to the cart as shown in the figure below [2]. The pendulum cannot maintain balance and will fall towards its downward position.


Figure 1 – Inverted Pendulum Model (Kim, Park, and Oh).

The objective of the inverted pendulum experiment is to keep the pendulum in an upright position when impulses or fluctuations in the horizontal direction occur. This objective has to be achieved with the understanding that the equilibrium at ϴ = 0° is marginally stable. As the DC motor has only limited power and the track has finite length, there exist certain states of the physical system from which the pendulum cannot be steered back to the upright position. Therefore, certain parameters characterize the system state for which the system stability can always be maintained.
When a biped robot is supporting its body on one leg, it can be represented by a single inverted pendulum. The pendulum is composed of a grouped-mass center of gravity and a massless shaft with the length l [3]. The shaft links the center of gravity with the ankle joint of the supporting leg [4]. In the inverted pendulum model, the potential energy is at its maximum when the center of gravity is passing the normal axis. This is useful information because when our robot is walking, the robot keeps stationary when it reaches its maximum potential energy. This characteristic allows biped robots to be modeled with the simple inverted pendulum. When the biped robot reaches its maximum potential energy, this state is called Zero-State-Point. In order to have the robot dynamically walk, the figure below illustrates the dynamics of the biped robot [3].


Figure 2 – Zero-State-Point (Li and Chen).

From the figure above, two simple assumptions can be derived. First, the contact between a robot and the surface is point-contact. Second, the robot’s motions in sagittal and lateral planes are independent. From the first assumption, the point-contact essentially means the ankle joint of the supporting foot is passive. The second assumption shows the effect of the lateral motion on the sagittal dynamics can be ignored because the lateral side to side shaking motion is very small. This allows the dynamics in the sagittal and lateral planes to be handled separately. The motions of the inverted pendulum for the sagittal and lateral planes can be represented with the following equations.
̈
(1)

̈
(2)

and represent the pendulum’s angles in the sagittal and lateral planes respectively and represent the acceleration of gravity and the rod’s length respectively.
In the sagittal plane, the position of the center of gravity and the origin of the coordinates system lie in the ankle of the supporting foot as seen in the figure above. The position of the center of gravity can be calculated by:

(3)

(4)

Now, in order for the robot to move steadily, the robot must be able to demonstrate a walking patter, therefore, the pattern must be continuous and repeatable. An understanding of symmetry and periodic should be made. Through research, the periodicity and the symmetry of the gait contain the following restraints [4]:

(( ) )
(

)
(5)

| (( | ) )
(
) | (6)
To find the Zero State Point constraint, apply the following equation when the center of gravity passes the normal axis at

:

| (
| ) | (
) | (7)
| ̇(
| ) | ̇(
) | (8)

When walking, the switching of the gait occurs at the midway point of a leg swing, which occurs when is equals to

. By using that relationship, the following equations can be derived:

(( | ) ) | (
)
(9)
(
) | (10)

Using the equations for the motion of the inverted pendulum, the general differential equation can be expressed as:

| ( )
(11)
√
are the undetermined coefficients. | (12)

By using substitution, the equation of the pendulum angle can be derived as:

| ( )

(

) | (13)

(

)
(14)

These equations reveal that the trajectory of the center of gravity motion of the biped robot can be determined by the walking parameters in the sagittal plane. The equations for the lateral plane’s trajectory of the center of gravity derived in a similar fashion as well. The trajectory of the center of gravity constraint equations are:

(

) | (( | ) ) | (
) | (15)

(

) | (
) | (16)

is the lateral swing of the center of gravity in the cycle. As specified before, in order to have the robot walk in a dynamic motion, being able to keep the body of the robot in an upright position is critical [5].

Also, to implement the walking cycle of our robot one can use the inverted pendulum model to set the frequency in order to produce natural swings. The equation to find the frequency can be found by using the following equation,
√
(17)

The lateral swing amplitude of the pelvis can be derived via ZMP of the inverted pendulum. The equation of motion for a simple inverted pendulum can be expressed as:

̈ | (18)

By multiplying both sides by

, the equations becomes:

( ̈) | (19)
Since | , the equation can now be expressed as:
( ̈) | (20)

Where:

Therefore, the lateral displacement of the mass center is expressed as:

(

) | (21)

The sinusoidal component is obtained from the relation between the robot walking and the lateral displacement of the mass center.

Another model of a biped robot can be demonstrated as a sequence of seven rigid bodies. These bodies include the following parts, both feet, lower legs, upper legs, and the trunk/torso. The head is included in the torso. From the figure below found in a reference document, one can see the rigid bodies and their respective angels [1].


Figure 3 – Rigid Biped Model (Kondak and Hommel).

By using Kane’s formalism [6], the dynamical equations can be derived. Here is the form of the derived equation.

( ) ̇ | ( | ) | (22)

In the f function, q is the vector of generalized coordinates, which are angles in the ankles, knees, hip joints, and ω is the corresponding generalized velocities. The matrix function, M(q), takes into account the mass distribution and the vector function, f(q,ω), describes the effect of both inertial forces and gravity. This model allows us to describe the torques of the robot’s joints. The kinematic equation can be modeled with the following equation,

| ̇ ω | | (23)
2. Possible Controllers
Various designers have suggested suitable controllers to manipulate a walking cycle [2]. Before continuing, a description of a walking pattern must first be described. For the purpose of this report, let the following set of descriptions describe a complete walking cycle:
a. Stage 1: lift the right leg to its maximum flexion and height
b. Stage 2: lower the right leg until it makes complete contact with the ground
c. Stage 3: lift the left leg to its maximum flexion and height
d. Stage 4: lower the right leg until it makes complete contact with the ground e. Stage 5: This stage follows stage 1 or stage 2, and brings the robot to a sanding equilibrium point.
Designers used the above walking cycle description to propose a control algorithm that is composed of three control strategies [9]. These strategies are: a real time balance control strategy, a walking pattern control strategy, and a predicted motion control strategy. Each control strategy is composed of several controllers that correspond to the objective of the desired strategy. Essentially, this method divides the walking cycle into several walking stages and uses a controller switching strategy to obtain its desired objective. Listed below is a table of each strategy and it describes what stage it will operate in and its objective as well [9].

Figure 4 – Summary of Possible Controllers (Kim, Park, and Oh 2006).


These controllers could possibly work well for surfaces with a slight uneven floor; however, the robot is subject to fall down when the inclinations exceed a certain threshold. Designers have begun researching possible solutions to the uneven floors that present problems to the existing control algorithms. These solutions are but are not limited to: upright pose controller, landing position controller, and vibration reduction controller [2]. These solutions would then be added to the existing algorithm presented in the above table. Each controller is designed through mathematical models and experiments.

## Conclusion

This paper presented the theory for a control algorithm of a biped robot. The theory associated with the algorithm is largely based on the classical control inverted pendulum problem. By modeling the biped robot as a simple inverted pendulum, the walking pattern can make the robot walk more human like compared to the unnatural slow motion that most robots tend to display. The use of a feedback controller such as a sensor can be used so that the robot can adapt to the unevenness of the surface plane. An uneven surface can cause the robot’s system to become uneven even by a small fraction of a few degrees. Possible controllers were presented from past and present designers. Each aspect of the robot must be analyzed carefully when implementing a control algorithm. These elements include: hardware, software, and gait development. Designers and researching are connecting present algorithms to create an algorithm where a robot could possibly display large amounts of robustness with negligible interference from the floors inclination.

## References

[1] K. Kondak and G. Hommel, Control Algorithm for Stable Waling of Biped Robots, Technische Universitat Berlin, Institut fur technishe Informatik und Mikroelekronik, Germany.
[2] J. Kim, I. Park, J. Oh, Walking Control Algorithm of Biped Humanoid Robot on Uneven and Inclined Floor, HUBO Laboratory, Humanoid Robot Research Center, Department of Mechanical Engineering, South Korea.
[3] J. Li and W. Chen, Modeling and Control for a Biped Robot on Uneven Surfaces, Joint 48th IEEE Conference on Decision and Control and 28th Chinese Control Conference, Shanghai, China.
[4] S. Kajita, F. Kanehiro, K. Kaneko, K. Fujiwara, K. Harada, K. Yokoi and H. Hirukawa, Biped Walking Pattern Generation by Using Preview Control of Zero-Moment Point, in Proc. IEEE Int. Conf. on Robotics and Automation, Taipei, Taiwan
[5] M. Vukobratovic, and Y. Ekalo, Mathematical Model of General Anthropomorphic Systems, Math. Biosci.
[6] T. Kane and D. Levinson, Dynamics On Line: Theory and Implementation with Autolev. Kane Dynamics, Inc., 2000.
[7] M. Vukobratovic, B. Borovac, D. Surla, and D. Stokic, Biped Locomotion. Dynamics, Stabilty, Control and Application. Springer, 1990.
[8] F. Bahrami, R. Reiner, M. Buss, and G. Schmidt, Optimal Trajectories for Paraplegic Patients Raising from a Chair by Means of FES: Preliminary Results, in Neuroprosthetics, from basic reseach to clinical application (A. Pedotti, F. Ferrarin, J Quintern, and R. Reiner, eds.) Springer, 1996.
[9] J. Y. Kim, I. W. Park, J. H. Oh.: Experimental realization of dynamic walking of the biped humanoid robot KHR-2 using zero moment point feedback and inertial measurement. Advanced Robotics. 2006.

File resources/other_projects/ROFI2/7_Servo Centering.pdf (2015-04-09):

# EE 400D

# Electrical Engineering Design Seminar and Project


# How to Calibrate Servos

# Isauro Ramirez

# November 27, 2012

## How to Center Servos:

This document will illustrate how to calibrate servos using the Arduino Mega 2560 microcontroller. These sets of instructions were used with the calibration of the servos used in the biped robot ROFI. The Arduino program implements a simple code that centers a single servo at a time. The program was used to center each servo before starting to build ROFI and it was also used during the build as well. There is no need for an external power supply with the use of the following program. A computer supplies enough power to the Arduino. Also, it is important to note that one needs to unplug the USB cable before he or she change servos so that the servo connection pins aren’t shorted together.

1. Materials Needed:
- Arduino Mega 2560
- 12 Servos (ROFI)
- USB Cable
- Arduino IDE Software installed on computer
- Servo Centering Program
- Jumper Wires
2. Instructions:
- Arduino IDE can be downloaded from the following link
- http://arduino.cc/en/Guide/HomePage
- Choose appropriate software for your computer
- Connect the Mega board via the USB Cable
- Install the USB drivers to enable your computer to recognize the Arduino device.
- Open the Arduino IDE application that you downloaded on your computer
- Select the Mega 2560 from the drop down menu “Tools/Board”
- Download the center servo source file from http://www.projectbiped.com/prototypes/rofi/programs/center-servo
- Upload the program to your Arduino Mega board
3. Wiring:
- Make the following connections
i. Black/Brown wire: GND/Ground Pin
ii. Red wire: Vin Pin
iii. Orange/Yellow wire: digital pin 8 (PWM)
- Please reference the following figure. Figure can be found http://www.projectbiped.com/prototypes/rofi/programs/center-servo


Figure 1 – Wiring Servo (Project biped Rofi 2012).

4. After wiring the servo to the Arduino board, plug the board into your computer with a USB cable. The servo should stop moving once it has been centered.
5. Jonathan Dowdall, the inventor of the biped Robot, ROFI, created the free software used to center the servos. Here is the source code that can be downloaded from his website given above.

#include <Servo.h>

Servo myservo; | // create servo object to control a servo
| // a maximum of eight servo objects can be created
int pos = 0; | // variable to store the servo position
void setup()
{
myservo.attach(8); // attaches the servo on pin 9 to the servo object }
void loop()
{
myservo.write(90); // tell servo to go to the home position }

## References/Comments:

1. http://www.projectbiped.com/prototypes/rofi/programs/center-servo
2. http://arduino.cc/en/Guide/HomePage

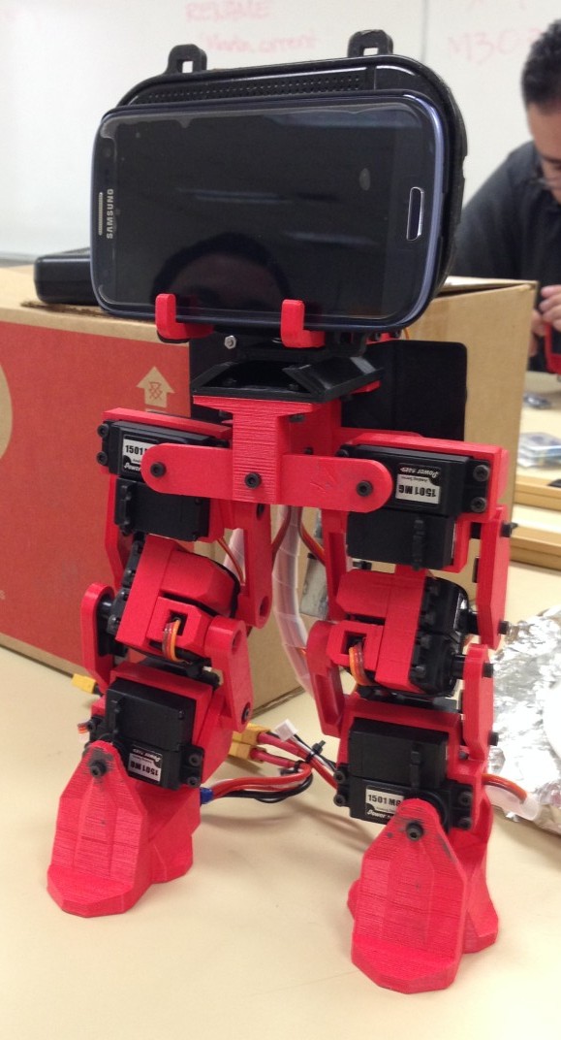
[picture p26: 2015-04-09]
resources/other_projects/fullROFIA-e1385011889413.jpg

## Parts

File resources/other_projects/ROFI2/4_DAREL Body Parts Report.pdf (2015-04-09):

1 | P l u m a | 3 0 N o v e m b e r 2 0 1 2

## ROFI – Next Generation Head – DAREL

by Mike Pluma

### Table of Contents

## Objectives For New Design

The ROFI model is the fifth robot prototype design by Jonathan Dowdall on ProjectBiped.com. (http://www.projectbiped.com/prototypes/rofi) It is primarily statically balanced. Static balance means that the robot's servo movements are pre-programmed and as such pre-balanced. Jonathan describes ROFI as semi-dynamically balanced because it also uses accelerometer feedback from the on board Android tablet to balance itself. Our goal with DAREL is to incorporate a more advanced Android device with more on board sensors. These additional sensors will be used to generate more positional feedback which can be used for more dynamic balance. The following is a breakdown of design objectives.

- Main objective: move toward Dynamic Balance
- Raise center of gravity by moving the batteries out of the feet
- Re-design the foot
- To address lack of battery
- Narrower foot-print
- "Organic Curves"
- Secondary Objective: Incorporate internal phone sensors
- Re-design "Body"
- Re-orient phone to take advantage of back camera
- Devise mount system to adapt to size of available phone (upgrade capable)
- Make room for Batteries, Gyro, Ultrasonic/IR sensor
- "Organic Curves"

## Execution of Objectives

The ROFI model has the batteries in the feet. The batteries are somewhat heavy and having them in the feet gives inherent stability to the robot. Dynamic balance is not about inherent stability, so to add some instability we raise the center of gravity by incorporating the batteries into the body. Moving the Batteries means that we can redesign the foot aesthetically and address some structural issues at the same time. The objective of using a more advanced Android device for its internal sensors brings a few issues. These more advanced devices are typically bigger than the tablet suggested in the ROFI design. To address this the DAREL head uses an adjustable bracket. It is adjustable because it is difficult to foresee the exact dimensions of the device that will suit the needs and the budget of the DAREL project. The phone brackets have rubber non-slip pads inside to secure the device as the robot will likely sway (if not fully fall over) during the development process as well as during normal walking.
Details for each of the new body parts and its assembly are described later in this document.

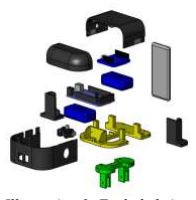
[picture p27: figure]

## Parts List:

- Uniform Foot
- Body Riser
- Body Base
- Phone Bracket Left
- Phone Bracket Right
- Body Shell Sides
- Body Shell Top
- Body Shell Dome

The same foot model is used for both the left and right foot. The foot is the same

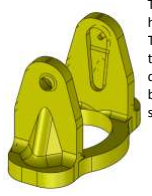
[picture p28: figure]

height as the ROFI foot but uses the "hollow" design element from the FOBO foot. The bearing hole has a thicker wall around it and a raised surround. This is because in the previous versions of the feet, the wall surrounding the bearing hole would snap during bearing insertion. The wall around the servo horn socket is also thicker. This is because in previous designs the servo horn put strain on the socket and over-stressed the foot. The foot is as long as the ROFI foot and as narrow.

The new body riser has a broader platform to mate with the new Body Base. They

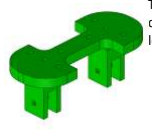
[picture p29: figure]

connect using more holes than the previous design. The new design still fits the old leg and hip parts from ROFI.

The Body Base attaches to the next gen body riser. The Batteries sit freely in the

head underneath the ardunio and behind the Midrange IR Sensor. The leads from the batteries run through the large access holes in the Body Base. The Arduino mounts to posts built into Body Base. The USB shield plugs into the arduino and is not mounted to the body directly. The Midrange IR Sensor mounts into the slot at the front of the Body Base. The gyro was not available at time of design, but could possibly be mounted onto a spare screw hole on the Body Riser.

Illustration 1: Exploded view of the DAREL Body

Illustration 2: DAREL
Foot

Illustration 3: DAREL
Body Riser

Illustration 4: DAREL
Body Riser

The phone brackets attach at the back of the Body Base. The screws go through the

slots on the brackets and the holes in the Body Base. The slots allow for the brackets to slide from side to side in order to adjust for the width of the phone. The high sides of the brackets support the phone in a vertical orientation. Some non-slip plastic or rubber pads are attached to the inside walls of the phone brackets for better grip onto the phone.

The Body Shell Sides attach to the Body Base at the front and rear sides. The

Midrange IR Sensor "eyes" go through the holes in the front. Holes on the right (DAREL's perspective) accomodate the USB and power jacks of the arduino, and fuse. The servo power switch is on his left.

The Body Shell Top attaches to the Body Shell Sides on the sides via the interlocking tabs and screws. The notch is to accomodate the USB cable that runs from the USB shield to the Arduino.

The Body Shell Dome joins the Body Shell Top and Body Shell Sides via the interlocking tabs and screws.

Illustration 5:
DARELs Adjustable
phone brackets

Illustration 6: DAREL
Body Shell Sides

Illustration 7: DAREL
Body Shell Top

Illustration 8: DAREL
Body Shell Dome

## Assembly Instructions

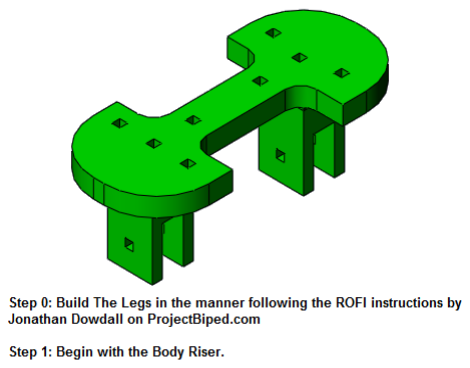
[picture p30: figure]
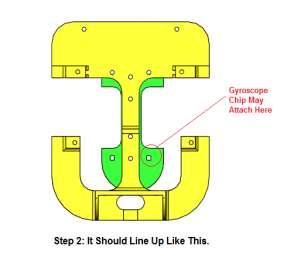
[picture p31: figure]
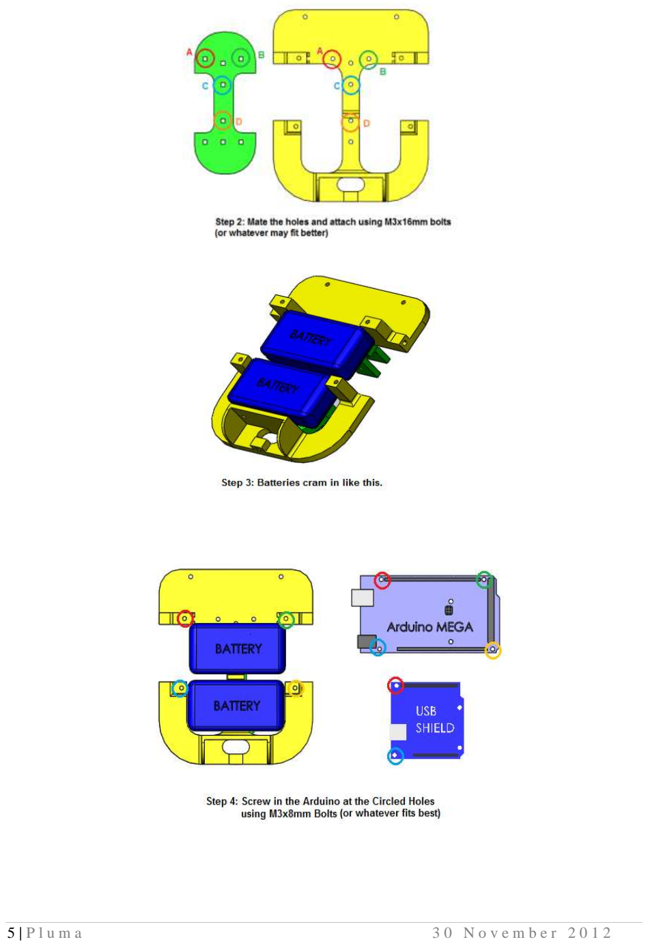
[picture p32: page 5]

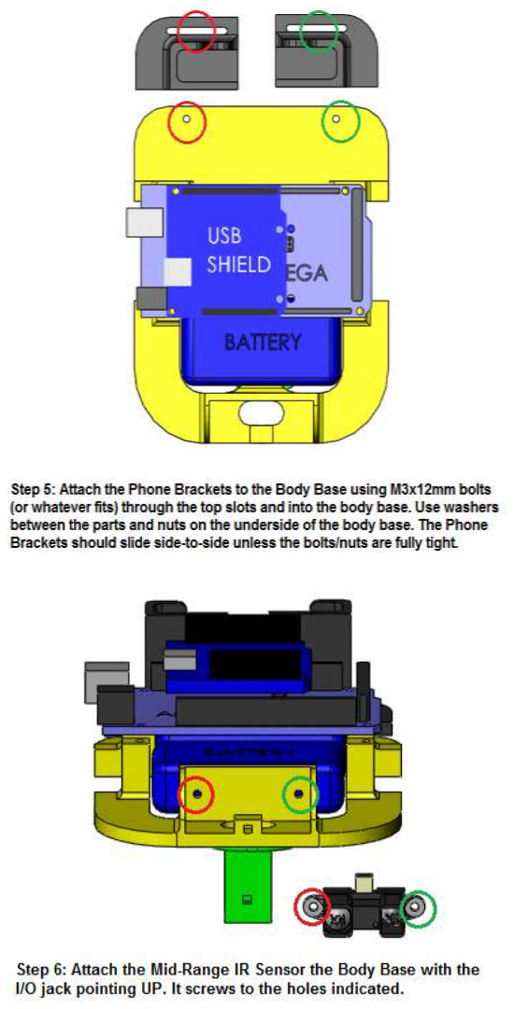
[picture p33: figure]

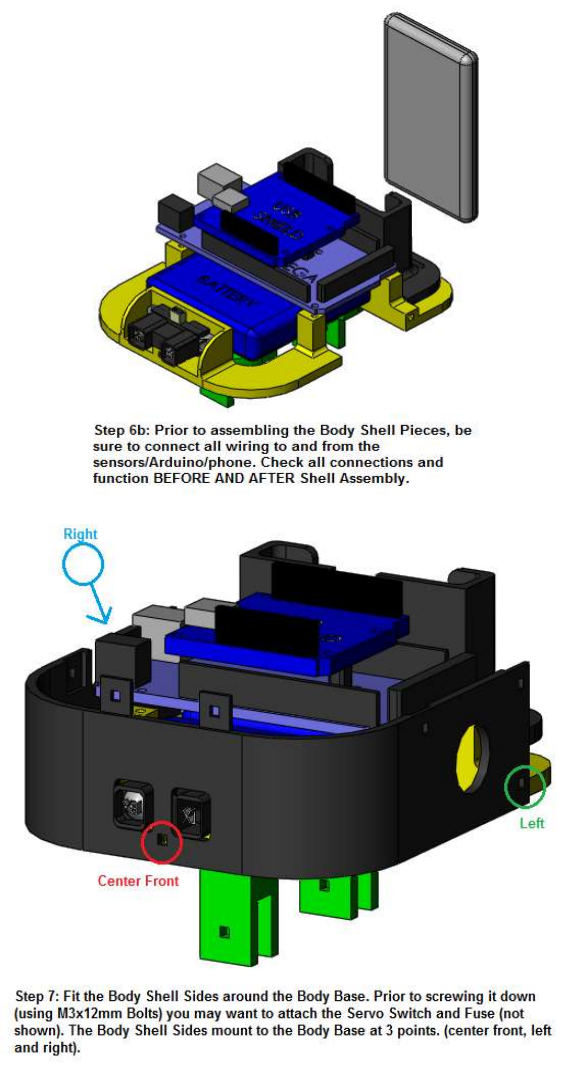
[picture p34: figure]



## Looking Forward

The phone bracket system was concieved to address the issue of various dimensions between phones. The ideal was to have a phone that has an internal Gyro and a front (screenside) camera. The same mounting brackets could be used in this case. The major difference is the placement/use of the IR RF. In the long view, the sensor package would use the device camera as the range finder, so the Midrange IR RF would be extraneous. If this is the case, the head as a whole could be mounted at 180 degrees and have the phone facing forward and use the front camera as the RF. Re-design of the head would be minimal.

Illustration 9: Fully Assembled DAREL Body


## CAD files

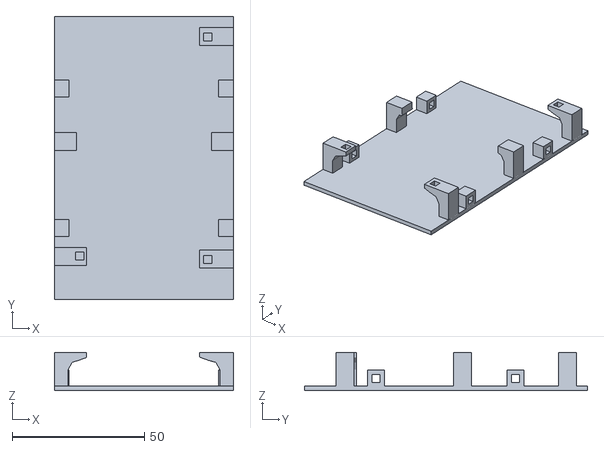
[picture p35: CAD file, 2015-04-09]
3d_models/printable_parts/body_panel_top_without_hole.stl
67.8 x 107.0 x 14.6

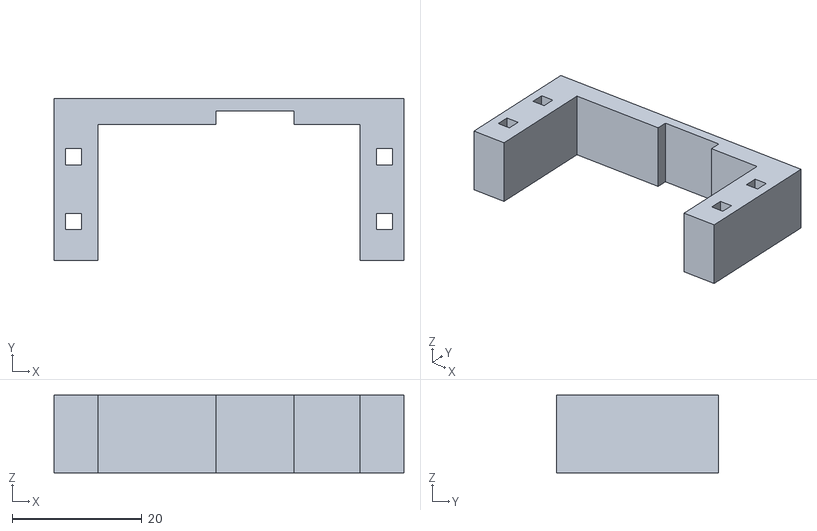
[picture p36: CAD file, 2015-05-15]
3d_models/solidworks_files/extra_servo_bracket.stl
54.0 x 25.0 x 12.0

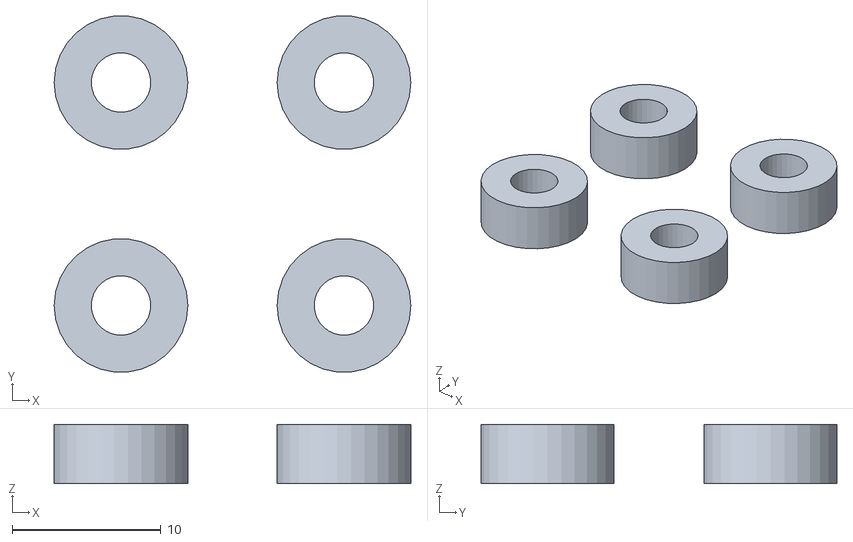
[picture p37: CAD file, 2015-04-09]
3d_models/printable_parts/Bearing.stl
24.0 x 24.0 x 4.00

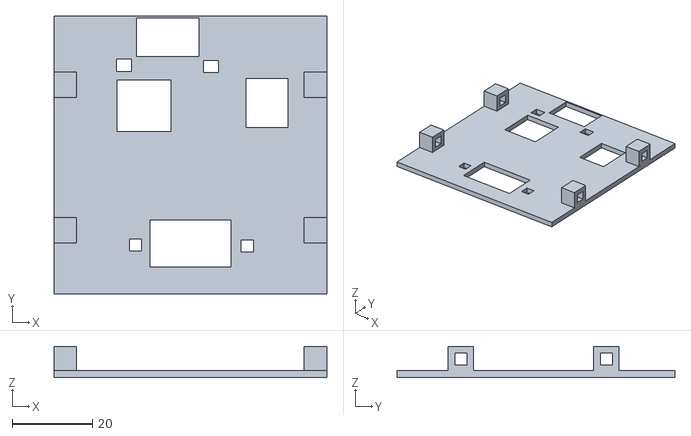
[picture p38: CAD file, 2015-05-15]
3d_models/solidworks_files/body_panel_back.stl
67.8 x 69.1 x 7.83

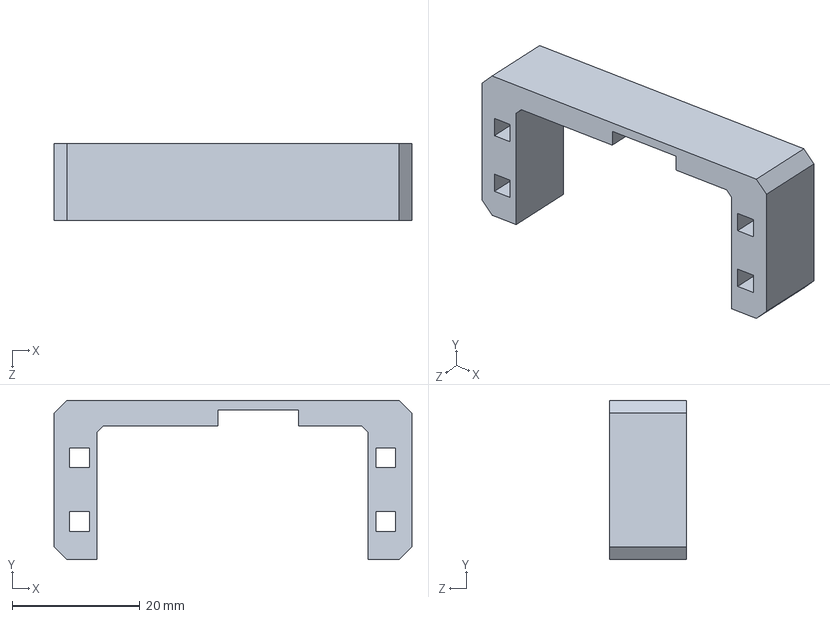
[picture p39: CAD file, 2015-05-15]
3d_models/solidworks_files/peca_suporte.SLDPRT
56.1 x 25.0 x 12.0 mm

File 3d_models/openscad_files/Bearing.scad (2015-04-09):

$fn=30;
module bearing(dext,dint){
	difference(){
		cylinder(4,dext/2,dext/2,center=true);
		cylinder(4,dint/2,dint/2,center=true);
	}
}

bearing(9,4);
translate([15,0,0]){
	bearing(9,4);
}
translate([0,15,0]){
	bearing(9,4);
	translate([15,0,0]){
	bearing(9,4);
	}
}

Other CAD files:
3d_models/printable_parts/peca_suporte.STL

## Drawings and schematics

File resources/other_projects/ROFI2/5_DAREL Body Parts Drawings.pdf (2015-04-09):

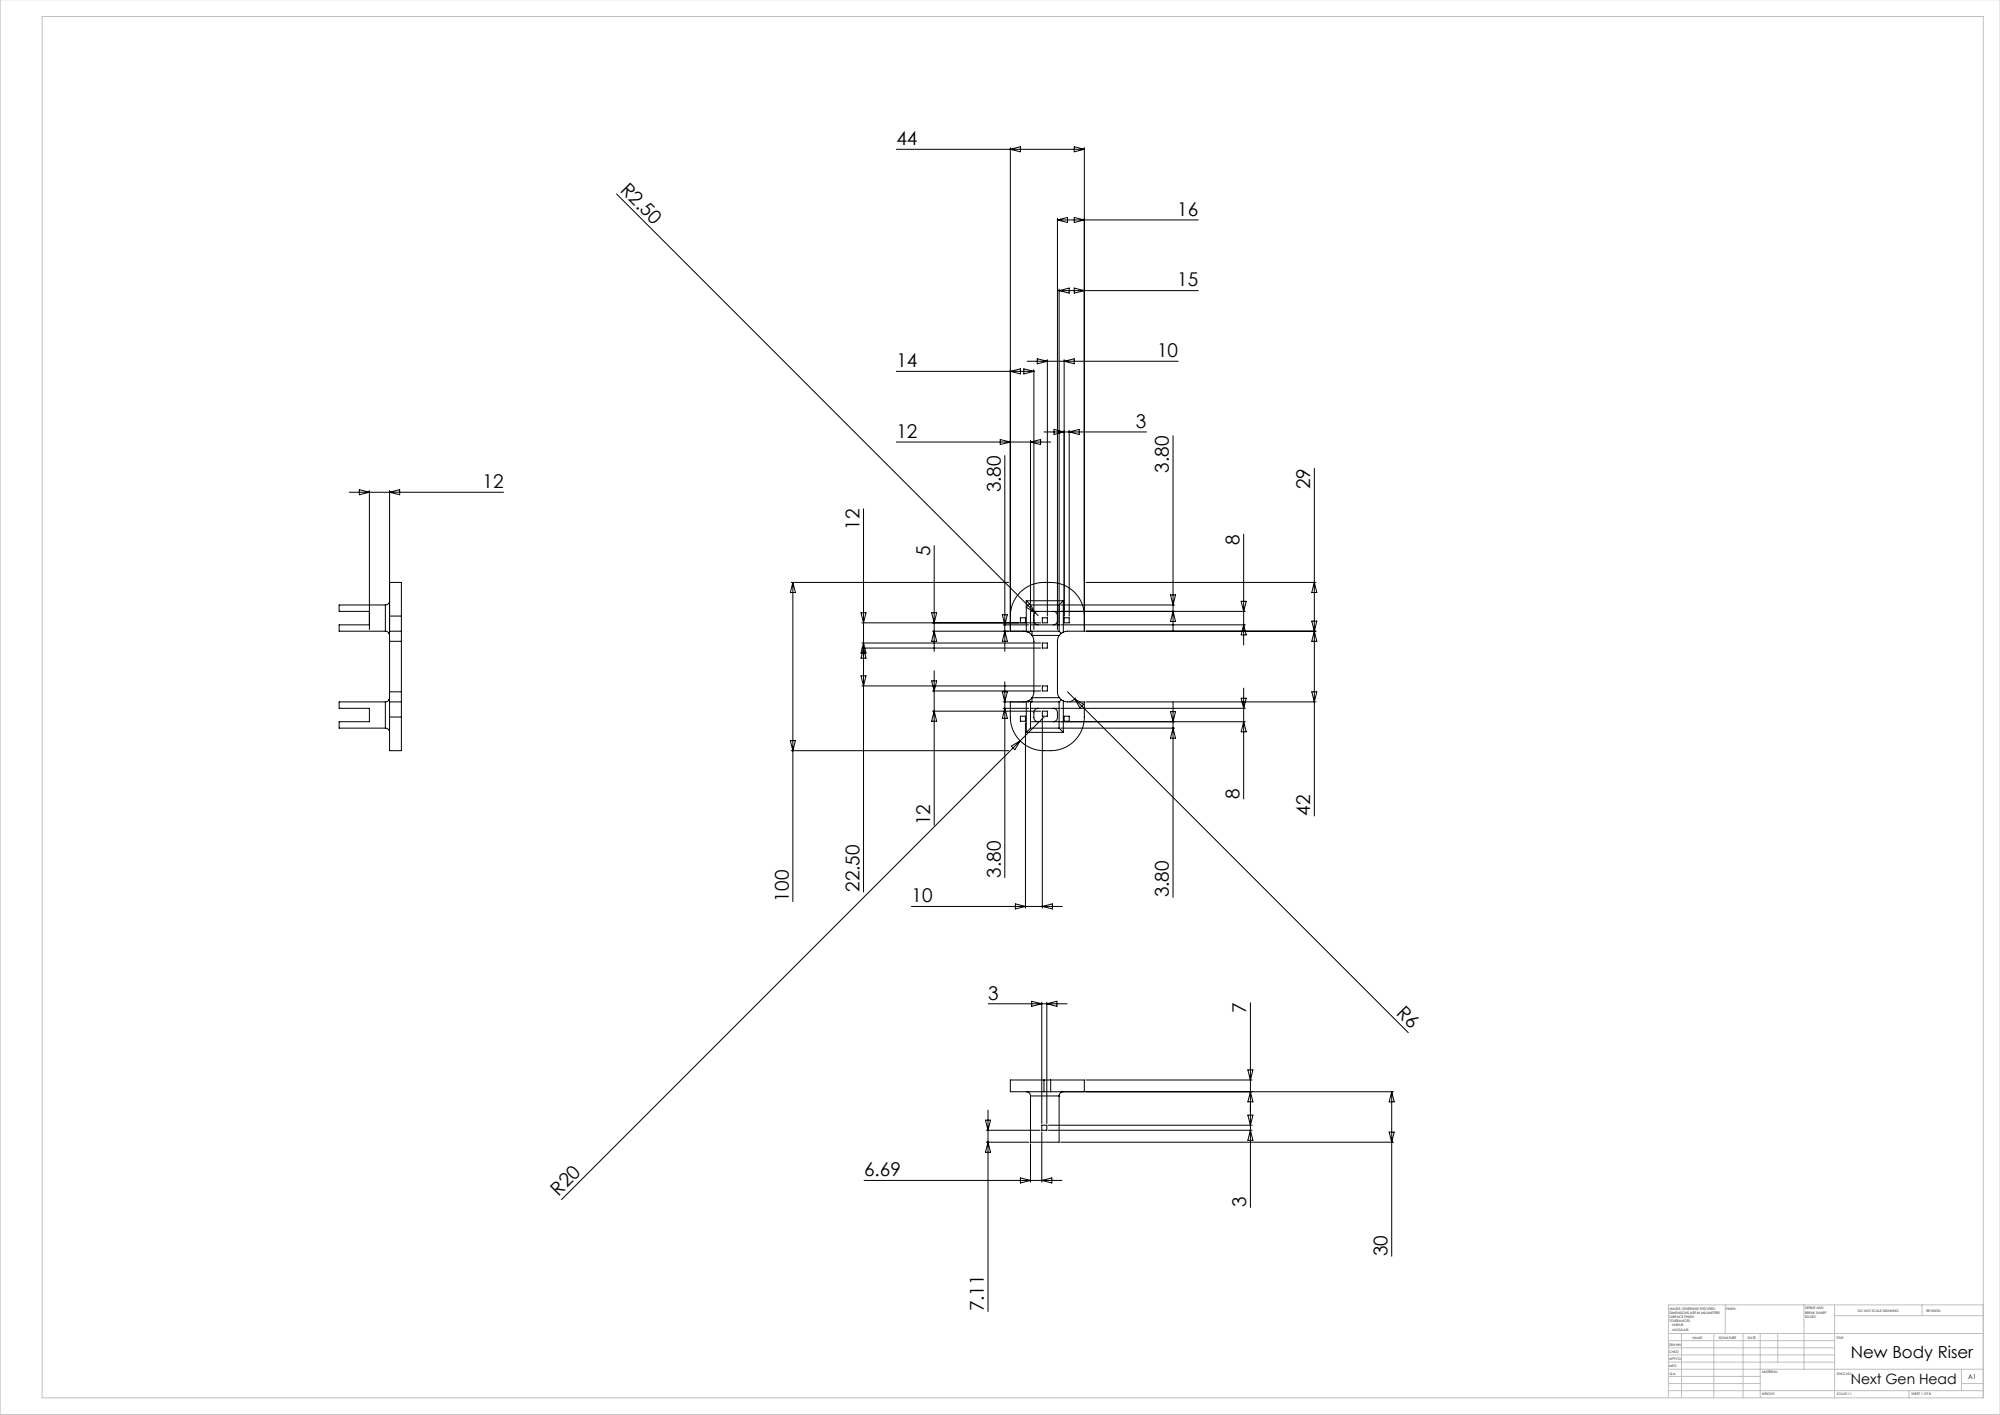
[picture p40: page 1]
SCALE:1:1; SHEET 1 OF 8; DO NOT SCALE DRAWING; REVISION; DEBUR AND BREAK SHARP; UNLESS OTHERWISE SPECIFIED:; FINISH:

DIMENSIONS ARE IN MILLIMETERS
SURFACE FINISH:
TOLERANCES:
LINEAR:
ANGULAR:

NAME | SIGNATURE | DATE | | | | TITLE: New Body Riser
Q.A | | | | MATERIAL: | Next Gen Head WEIGHT: DWG NO. | A1

DRAWN
CHK'D
APPV'D
MFG

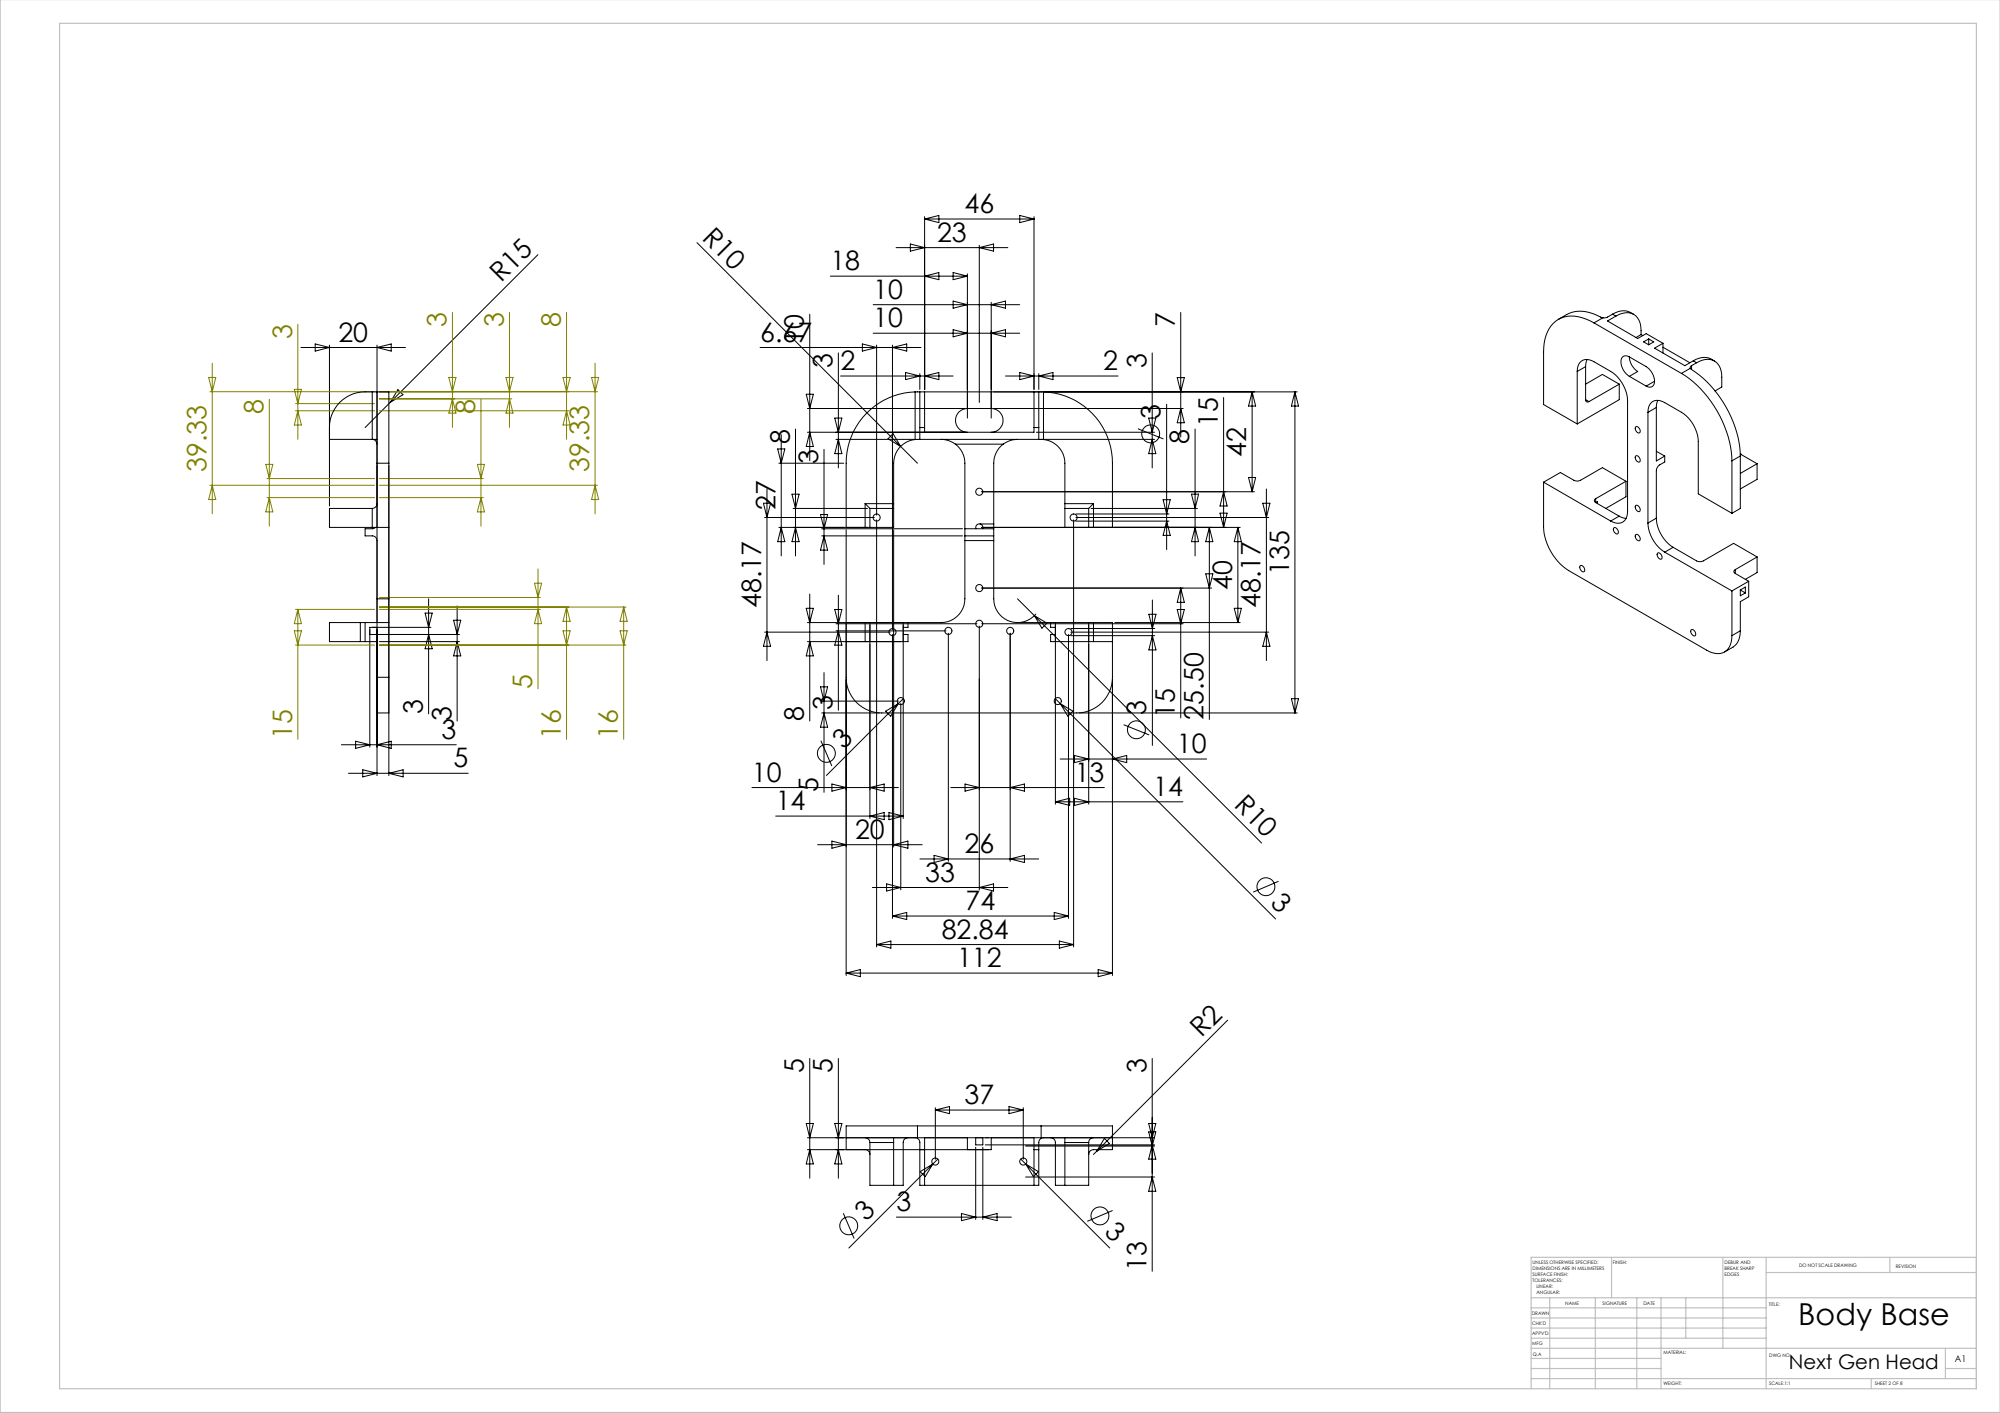
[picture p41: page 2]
Body Base; DO NOT SCALE DRAWING; REVISION; DEBUR AND BREAK SHARP; UNLESS OTHERWISE SPECIFIED:; FINISH:

DIMENSIONS ARE IN MILLIMETERS
SURFACE FINISH:
TOLERANCES:
LINEAR:

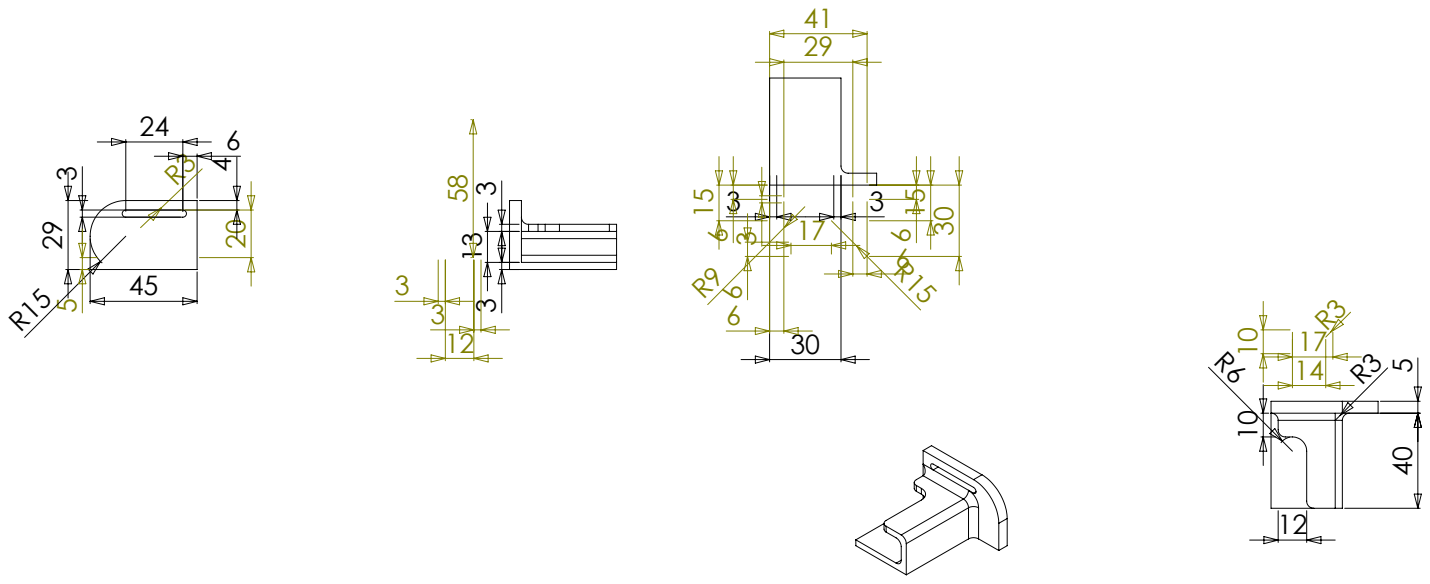
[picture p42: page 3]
Phone Bracket; DO NOT SCALE DRAWING; REVISION; DEBUR AND BREAK SHARP; UNLESS OTHERWISE SPECIFIED:; FINISH:

DIMENSIONS ARE IN MILLIMETERS
SURFACE FINISH:
TOLERANCES:
LINEAR:

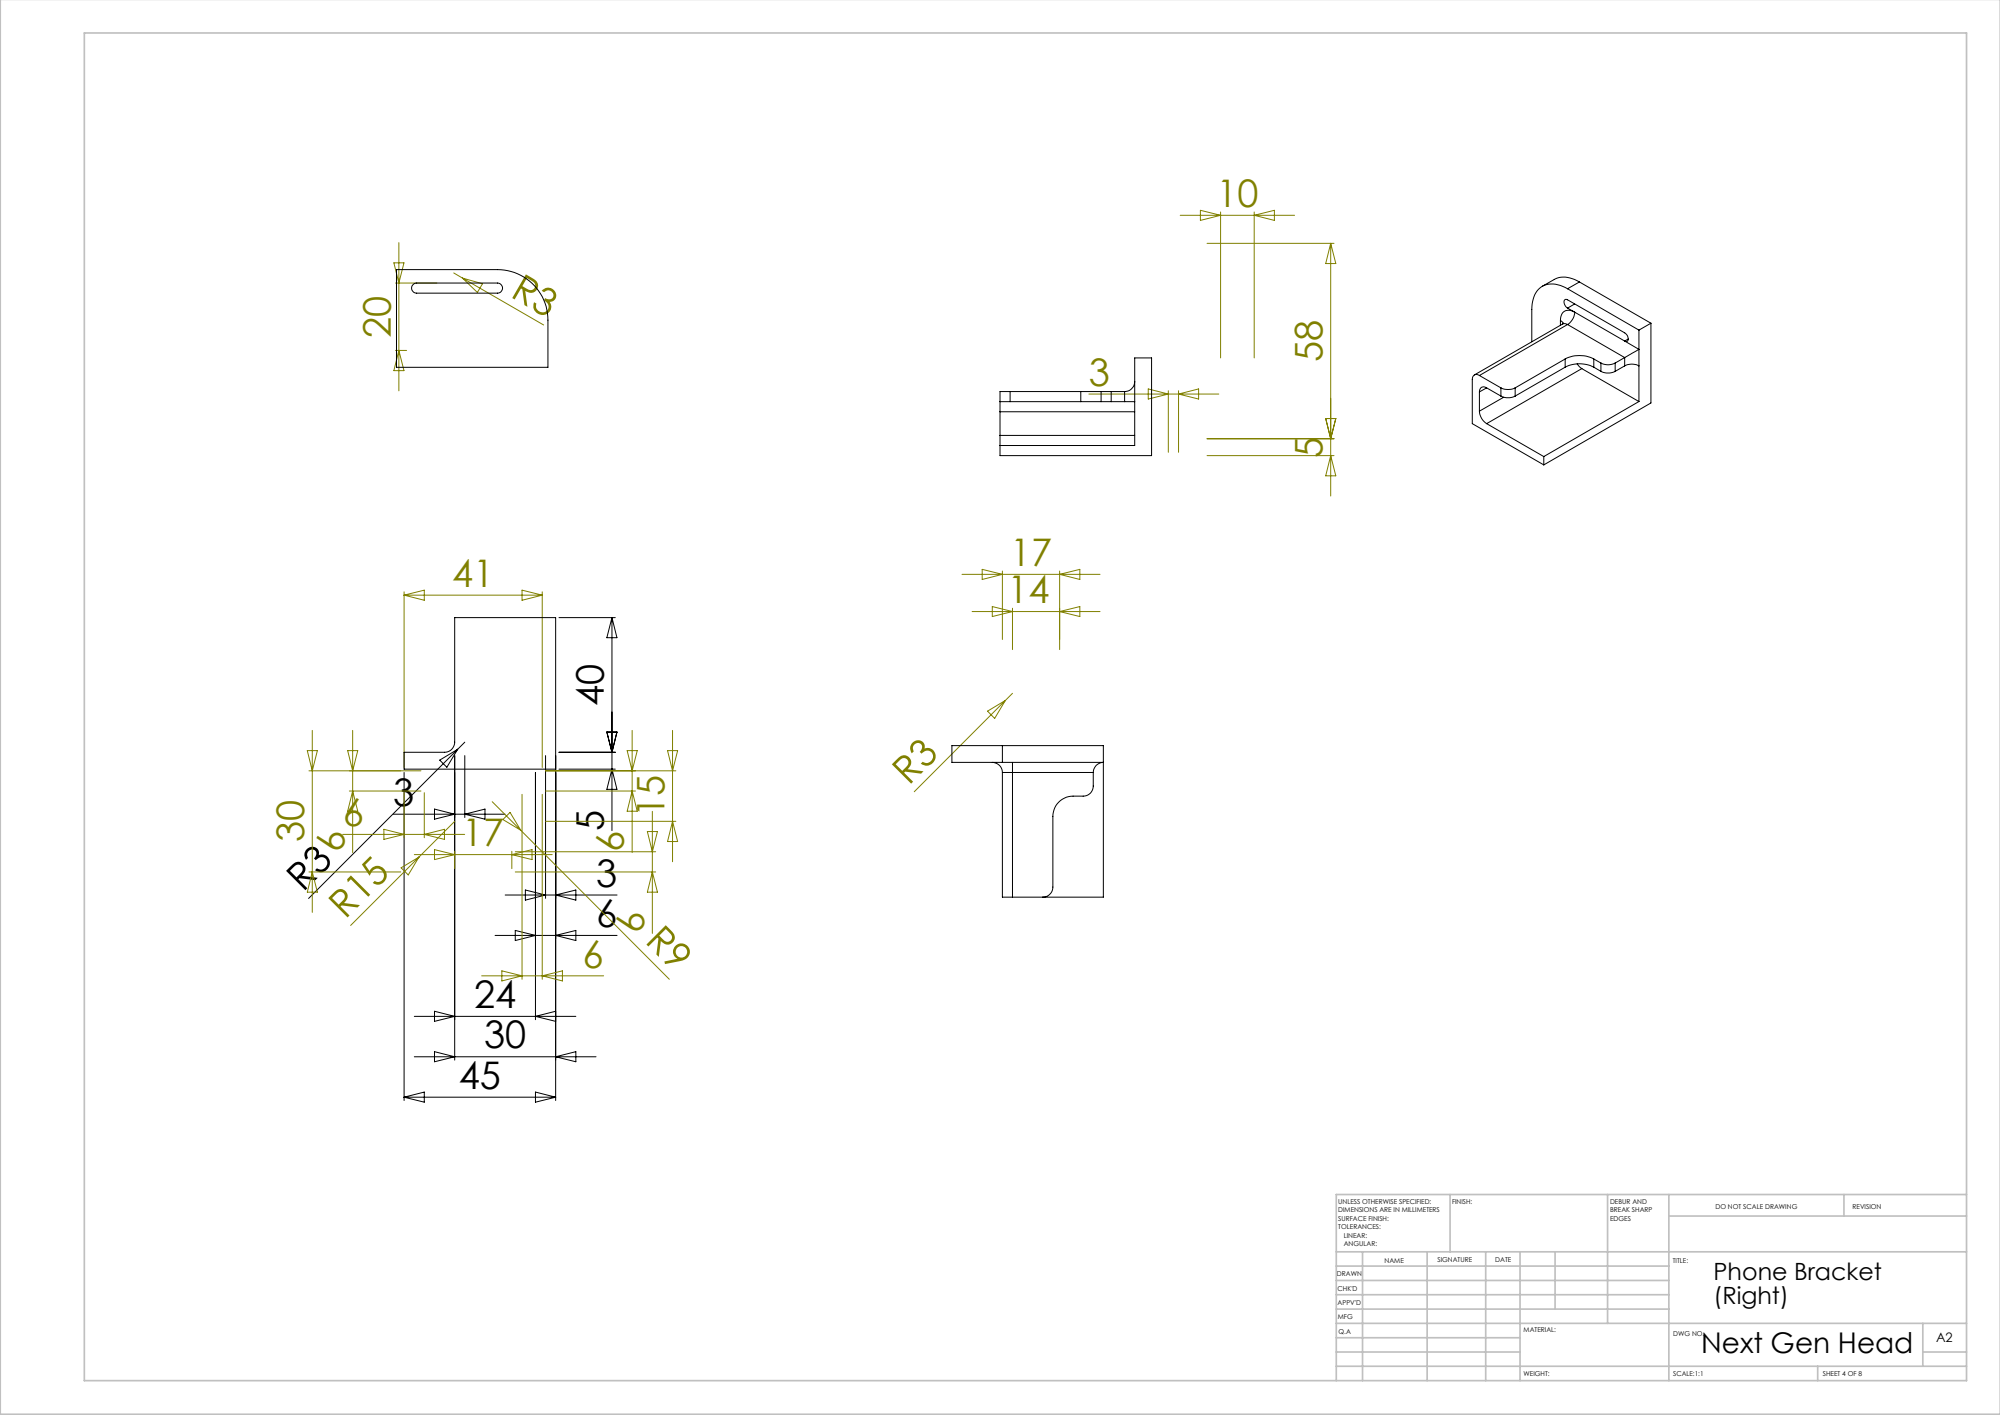
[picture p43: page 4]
DO NOT SCALE DRAWING; REVISION; DEBUR AND BREAK SHARP; UNLESS OTHERWISE SPECIFIED:; FINISH:

DIMENSIONS ARE IN MILLIMETERS
SURFACE FINISH:
TOLERANCES:
LINEAR:
ANGULAR:

NAME | SIGNATURE | DATE | TITLE: Phone Bracket (Right)

DRAWN
CHK'D

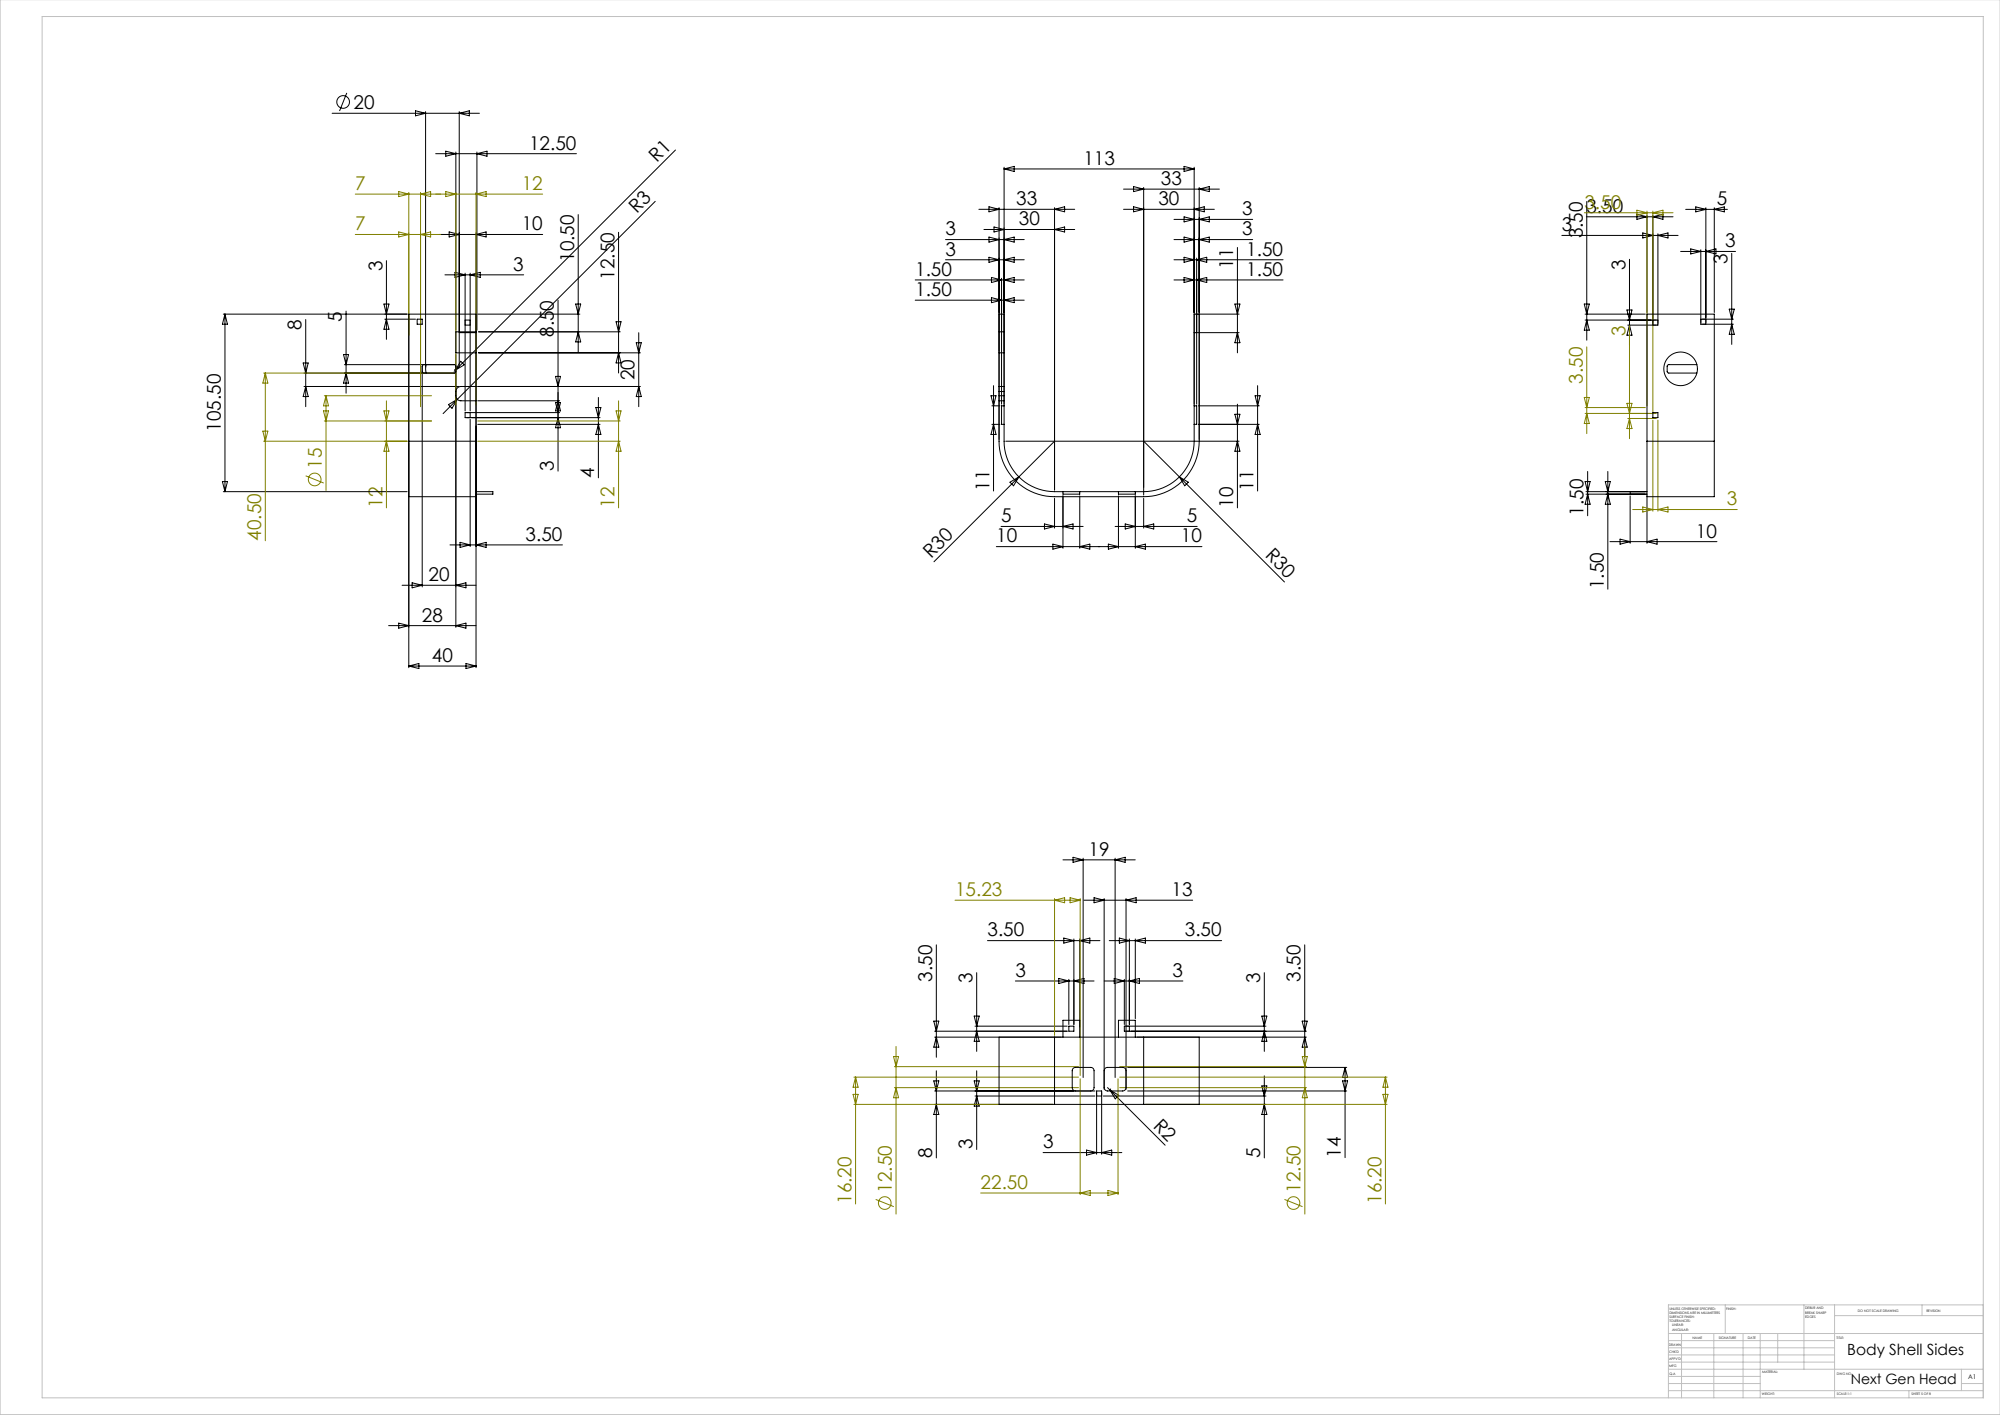
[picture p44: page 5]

Body Shell Sides

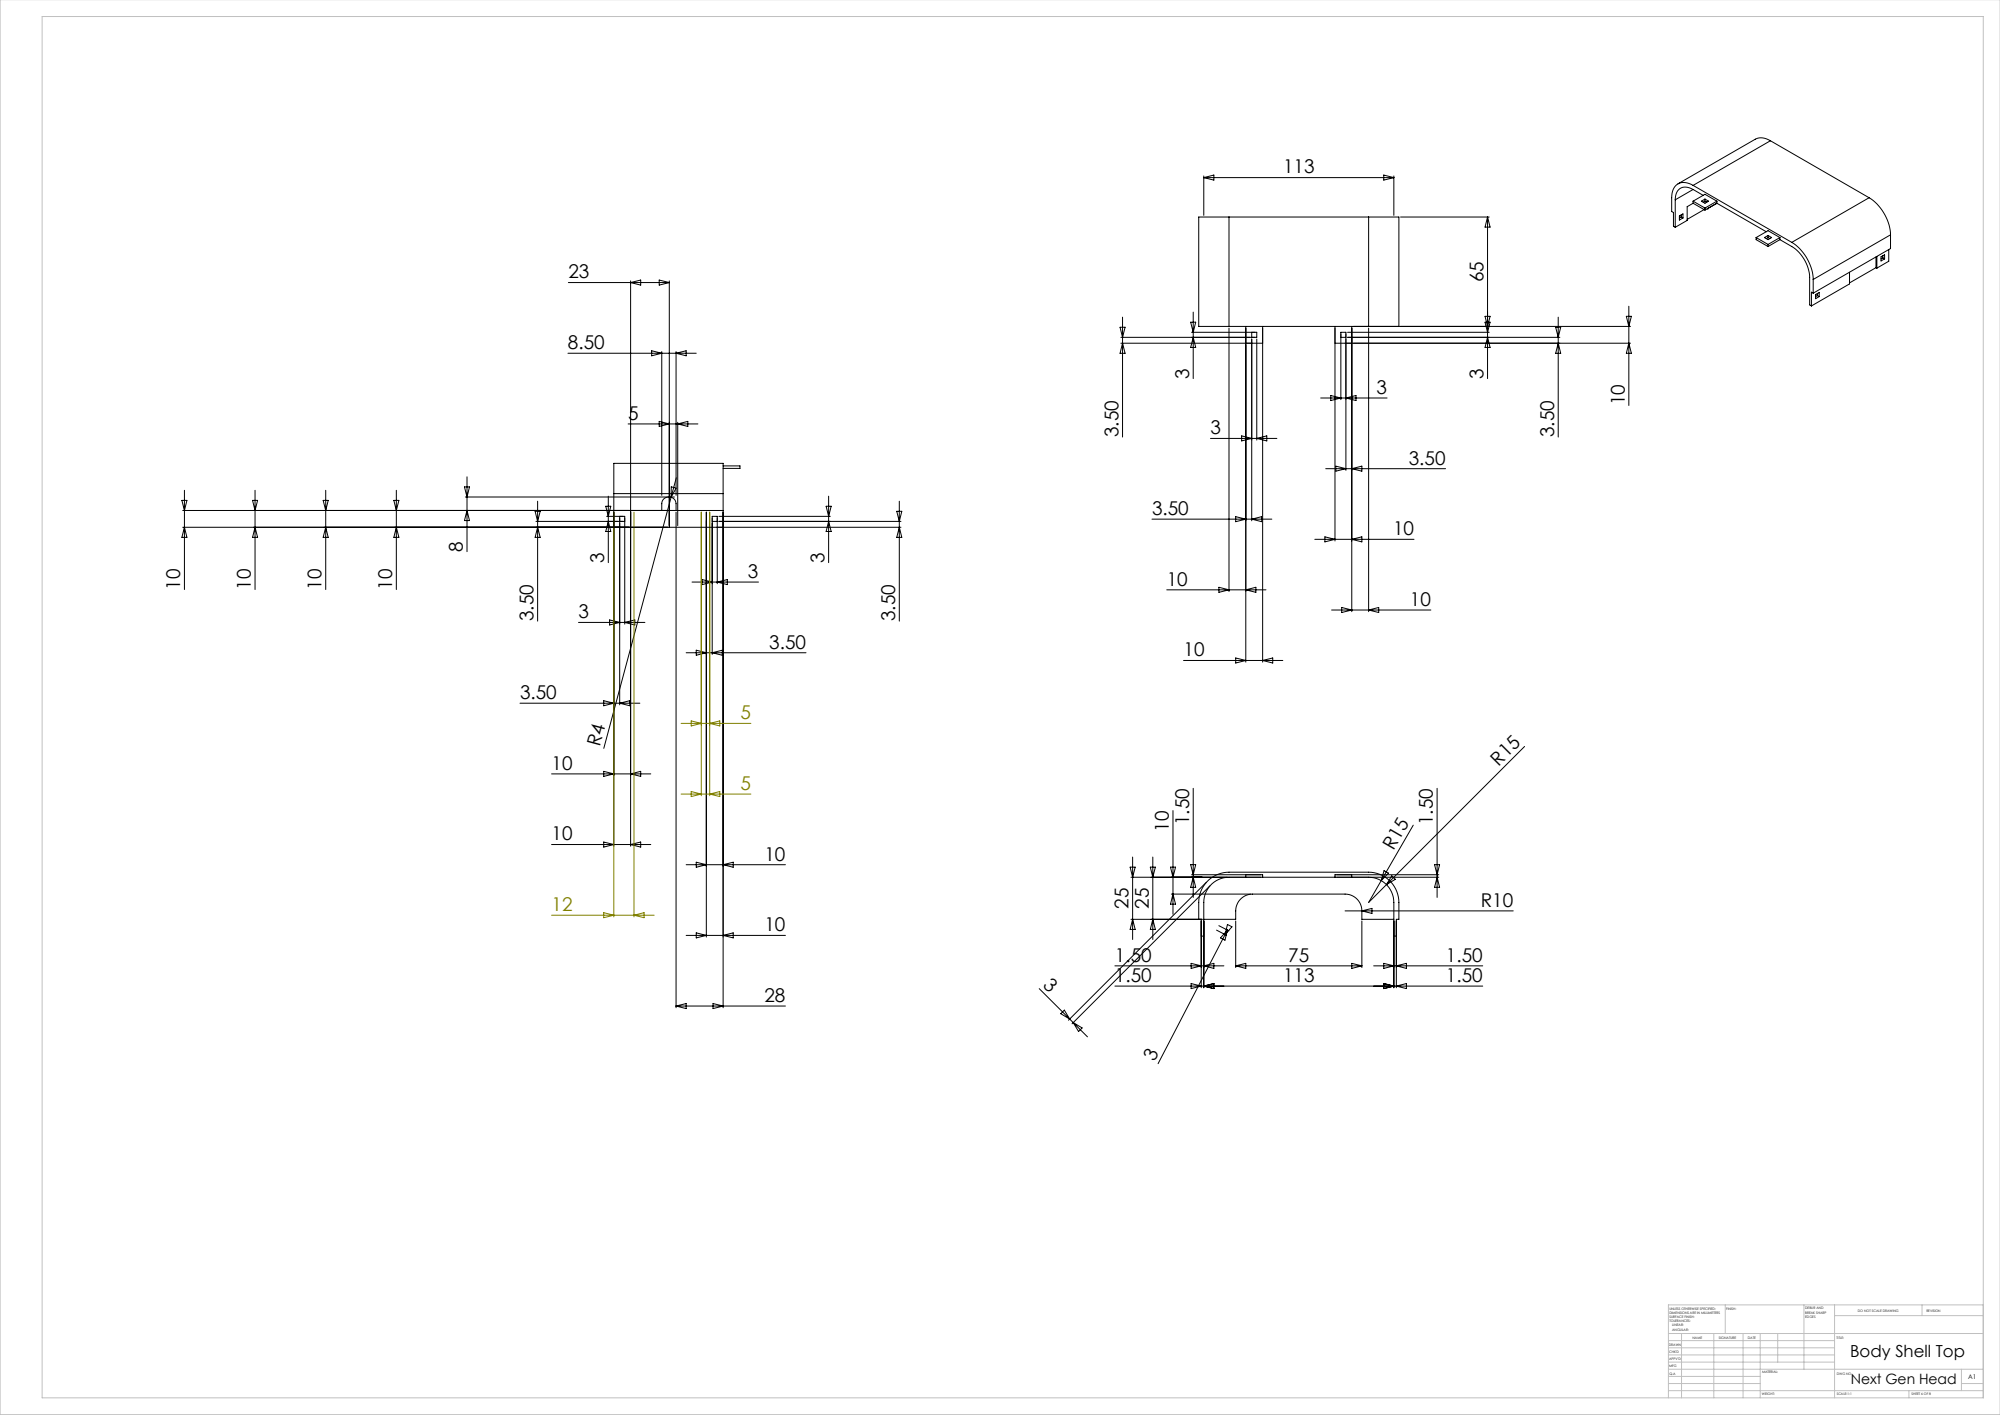
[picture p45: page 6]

Body Shell Top

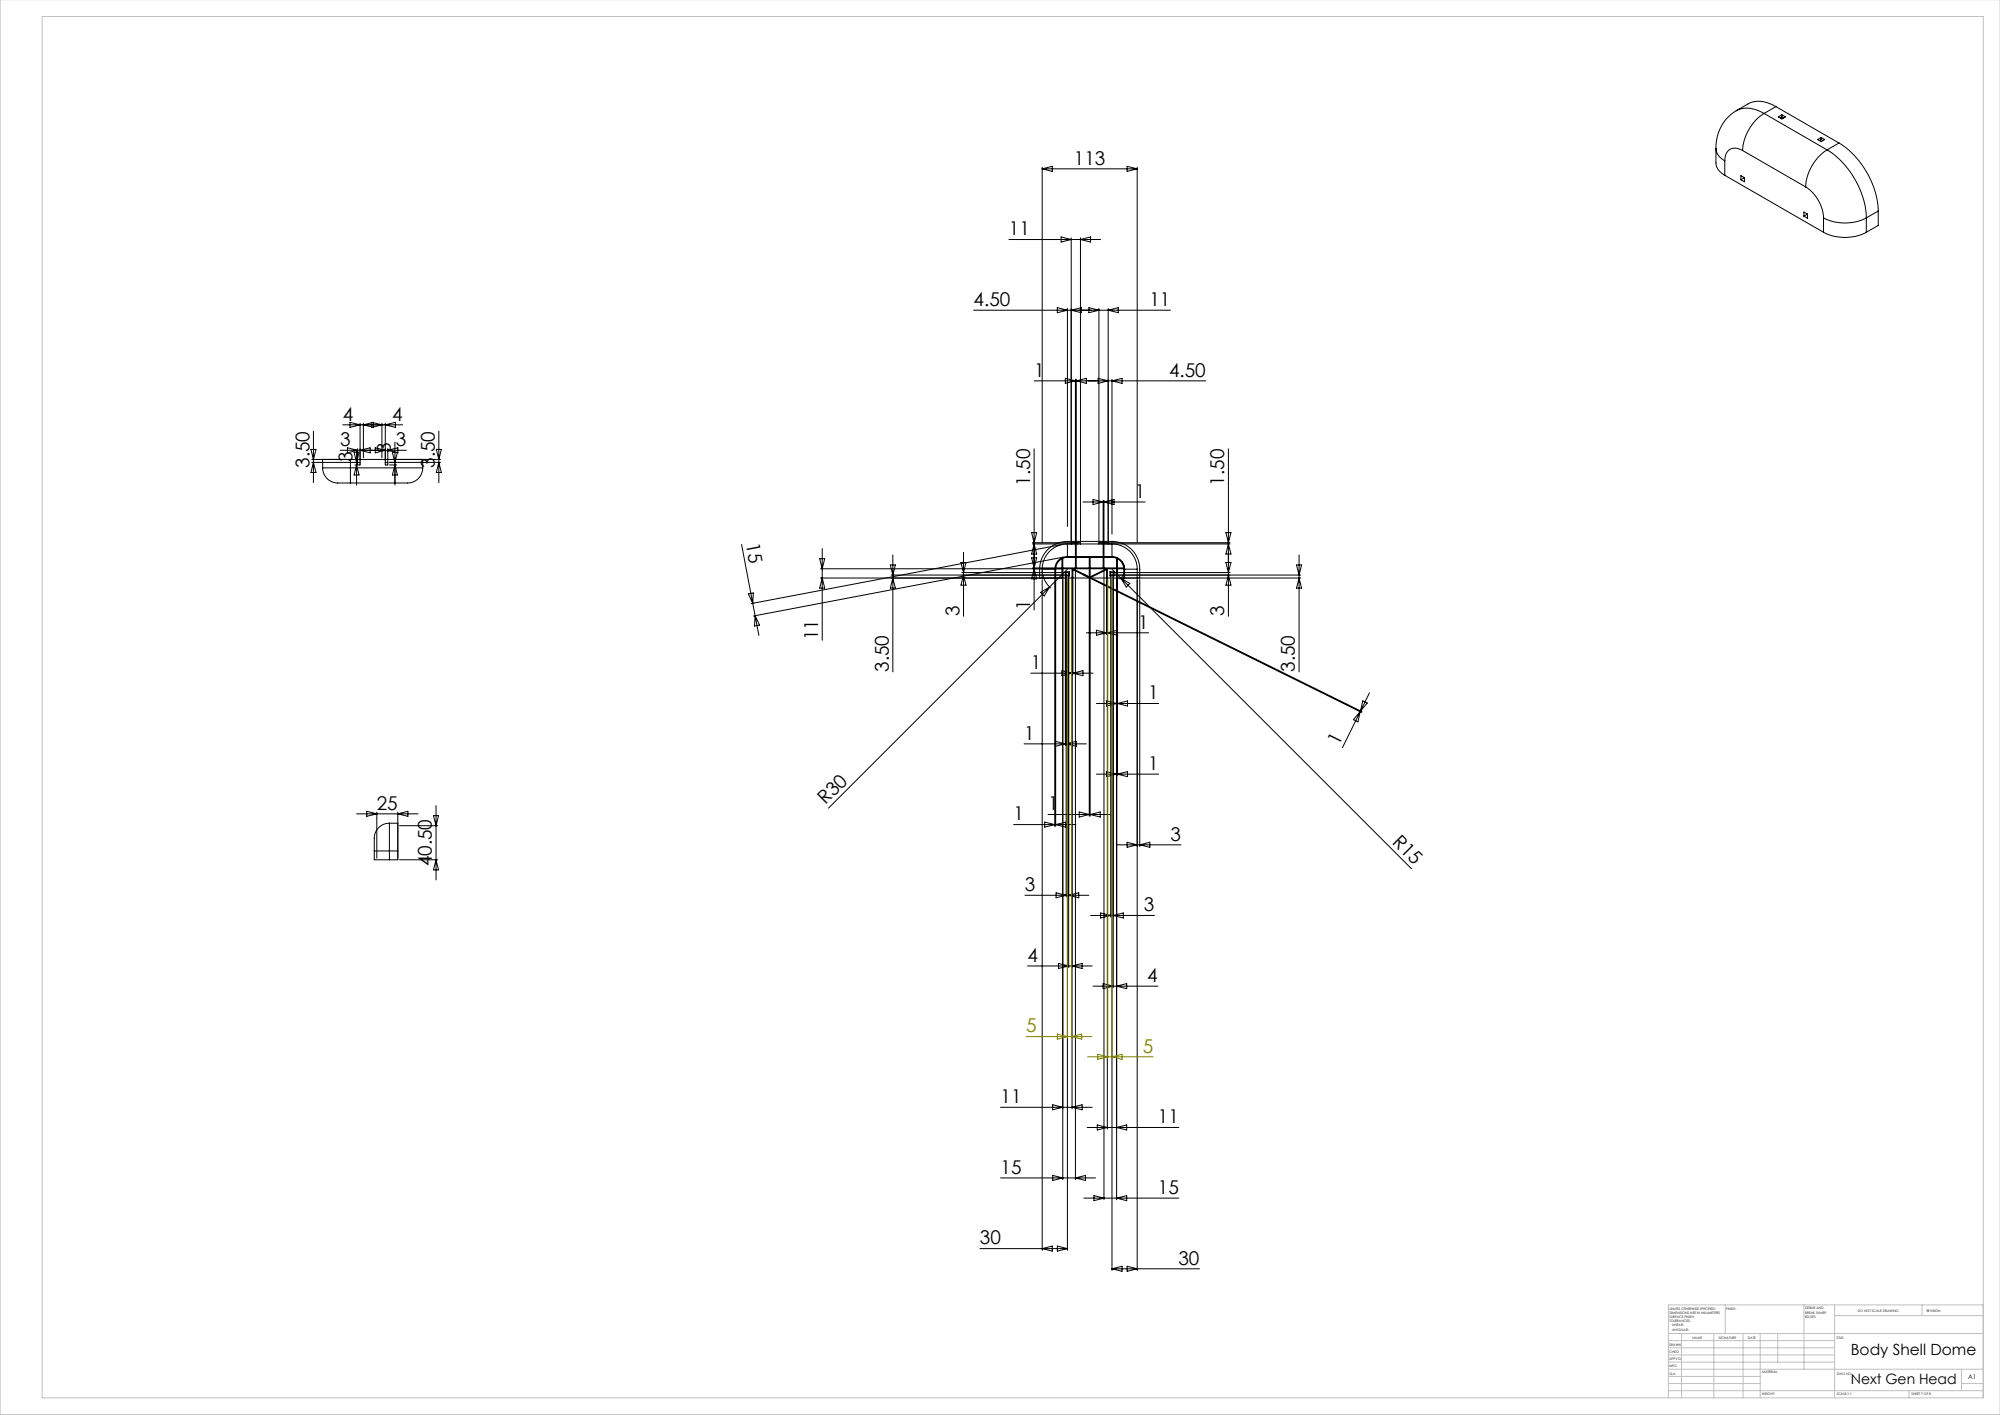
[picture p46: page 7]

Body Shell Dome

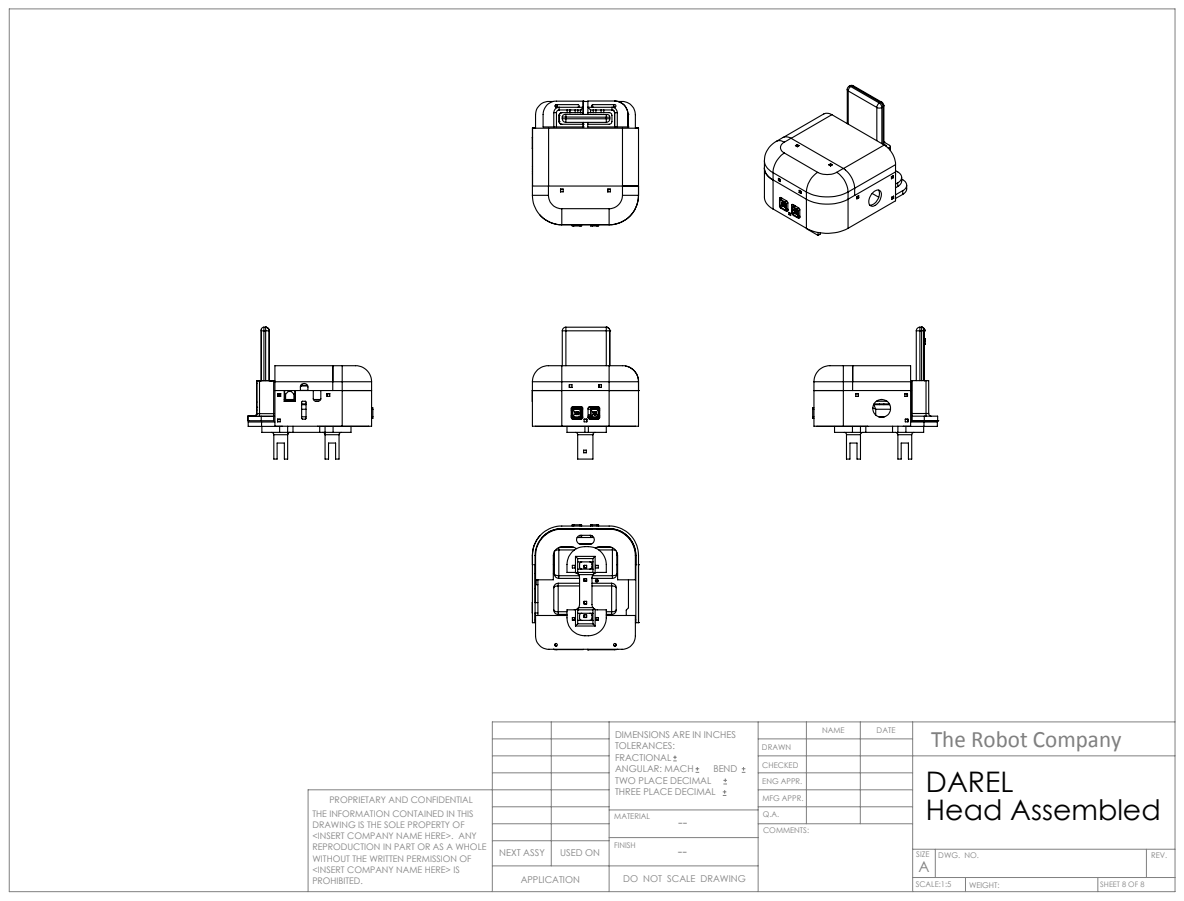
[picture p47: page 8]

DIMENSIONS ARE IN INCHES TOLERANCES: FRACTIONAL ANGULAR: MACH BEND TWO PLACE DECIMAL THREE PLACE DECIMAL | | NAME | DATE | The Robot Company

DRAWN
CHECKED | | | DAREL Head Assembled
ENG APPR.

PROPRIETARY AND CONFIDENTIAL THE INFORMATION CONTAINED IN THIS DRAWING IS THE SOLE PROPERTY OF <INSERT COMPANY NAME HERE>. ANY REPRODUCTION IN PART OR AS A WHOLE WITHOUT THE WRITTEN PERMISSION OF <INSERT COMPANY NAME HERE> IS PROHIBITED. | | | MFG APPR.

MATERIAL -- | Q.A.

NEXT ASSY | USED ON | FINISH --

SIZE A | DWG. NO. | REV.

APPLICATION | | DO NOT SCALE DRAWING

SCALE:1:5 | WEIGHT: | SHEET 8 OF 8

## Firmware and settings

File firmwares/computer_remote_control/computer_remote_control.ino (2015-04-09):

/*
//    ROFI remove control program. Version 1.0
//      This program allows ROFI to be actuated remotely (via USB cable) by a the Robot 
//      Poser application running on a desktop computer.
//
//    Copyright (C) 2012  Jonathan Dowdall, Project Biped (www.projectbiped.com)
//
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
//    You should have received a copy of the GNU General Public License
//    along with this program.  If not, see <http://www.gnu.org/licenses/>.
*/

#include <Servo.h> 

//////////////////////////////////////////////////////////////////////////////////////////////////////////////////////////////////////////////
// Constants
//////////////////////////////////////////////////////////////////////////////////////////////////////////////////////////////////////////////
const int  pingPin                   = 4;                           // digitial pin number on the arduino board that has the ping data line plugged into it
const int  numberOfServos            = 12;                          // there are 12 servos 
const int  messageLength             = 3 + numberOfServos * 2;      // the number of bytes in a message from the control program  

//////////////////////////////////////////////////////////////////////////////////////////////////////////////////////////////////////////////
//pin assignments
//////////////////////////////////////////////////////////////////////////////////////////////////////////////////////////////////////////////
/*
right leg
   Pin
    22 : ankle                      servo 0
    24 : lower leg                  servo 1
    26 : knee                       servo 2
    28 : middle leg                 servo 3    
    30 : upper leg                  servo 4
    32 : hip                        servo 5    
    
left leg
   Pin
    38 : ankle                      servo 6
    40 : lower leg                  servo 7
    42 : knee                       servo 8  
    44 : middle leg                 servo 9    
    46 : upper leg                  servo 10
    48 : hip                        servo 11   
*/
//////////////////////////////////////////////////////////////////////////////////////////////////////////////////////////////////////////////
int pins[numberOfServos] = {22,24,26,28,30,32,38,40,42,44,46,48};  // the pin for each servo 

//////////////////////////////////////////////////////////////////////////////////////////////////////////////////////////////////////////////
// Variables
//////////////////////////////////////////////////////////////////////////////////////////////////////////////////////////////////////////////
Servo servos[numberOfServos];  // create servo object to control a servo 

//////////////////////////////////////////////////////////////////////////////////////////////////////////////////////////////////////////////
void setup()
//////////////////////////////////////////////////////////////////////////////////////////////////////////////////////////////////////////////
{
  //initialize the servos
  InitializeServos();  
  
  //establist a connection with the remote controller (the poser application)
  EstablistConnection();
}

//////////////////////////////////////////////////////////////////////////////////////////////////////////////////////////////////////////////
void EstablistConnection()
//////////////////////////////////////////////////////////////////////////////////////////////////////////////////////////////////////////////
{
  //wait for a second to begin (keeps the communication line open in case a new program is being downloaded)
  delay(1000);  
  
  //start up the communication
  Serial.begin(9600);

  //buffer to hold the incoming message
  int inputBuffer[40];
  
  //broadcast our id until someone responds
  while(true)
  {
    //broadcast id
    Serial.print("ROFI");  
    
    //wait for a bit
    delay(100);  
    
    //look for a response
    if(Serial.available() > 1)
    {
      for(int b = 0; b < 2; b++)
        inputBuffer[b] = Serial.read();
        
      // make sure someone friendly is on the line
      if(inputBuffer[0] == (int)'h' && inputBuffer[1] == (int)'i')
      {
            Serial.print("connected");  
            break;
      }
    }      
  }  
}

//////////////////////////////////////////////////////////////////////////////////////////////////////////////////////////////////////////////
void InitializeServos()
//////////////////////////////////////////////////////////////////////////////////////////////////////////////////////////////////////////////
{  
  // Assign the correct pin to each servo.
  for(int s = 0; s < numberOfServos; s++)
    servos[s].attach(pins[s]);  
}

//////////////////////////////////////////////////////////////////////////////////////////////////////////////////////////////////////////////
void loop()
//////////////////////////////////////////////////////////////////////////////////////////////////////////////////////////////////////////////
{  
  // check to see if there are enough bytes on the serial line for a message
  if (Serial.available() >= messageLength) 
    // read the incoming message
    if( ReadMessage() )    
      // respond to the computer that is controlling the robot
      SendResponse();      
}

//////////////////////////////////////////////////////////////////////////////////////////////////////////////////////////////////////////////
bool ReadMessage()
//////////////////////////////////////////////////////////////////////////////////////////////////////////////////////////////////////////////
{
  // buffer to hold the incoming message
  int inputBuffer[100];

  // read the message
  int index = 0;
  while(Serial.available() > 0)
  {
    inputBuffer[index] = Serial.read();
    index++;
  }

  // make sure the message starts with "cmd" ... otherwise it isn't a valid message
  if(inputBuffer[0] == (int)'c' && inputBuffer[1] == (int)'m' && inputBuffer[2] == (int)'d')
  {
    //set the servo positions
    for (int servo = 0; servo < numberOfServos; servo++)
    {      
      // each servo position is sent as a 2 byte value (high byte, low byte) integer (from -32,768 to 32,767)
      // this number is encoding the angle of the servo. The number is 100 * the servo angle.  This allows for the
      // storage of 2 significant digits(i.e. the value can be from -60.00 to 60.00 and every value in between).
      // Also remember that the servos have a range of 120 degrees. The angle is written in positions
      // which range from a minimum of 800 (-60 degrees) and go to a maximum of 2200 (60 degrees)
      int value = word(inputBuffer[servo*2 + 1 + 3], inputBuffer[servo*2 + 0 + 3]);      
      
      // flip for the left leg.
      if(servo >= numberOfServos/2)
        value = map(value, -6000,6000,6000,-6000);
      
      servos[servo].write(map(value, -6000,6000,800,2200));              // tell servo to go to position in variable 'pos' 
    }

    // a valid messgae was received    
    return true;
  }  
  else
    // the message wasn't valid
    return false;  
}

//////////////////////////////////////////////////////////////////////////////////////////////////////////////////////////////////////////////
void SendResponse()
//////////////////////////////////////////////////////////////////////////////////////////////////////////////////////////////////////////////
{
  // Measure the distance 
  //unsigned int distance = MeasureDistance();
  unsigned int distance = 0;
  
  // Send the distance back (cast it to a byte array ... an int has a high and low byte).
  Serial.write((uint8_t*)&distance, 2);
  
  // Send the robot status (0 = happy).
  Serial.write((byte)0);

  // End the response.
  Serial.print("done");  
}
//////////////////////////////////////////////////////////////////////////////////////////////////////////////////////////////////////////////
// some of the code below was found on http://arduino.cc/en/Tutorial/Ping?from=Tutorial.UltrasoundSensor.  Thanks Arduino guys!
//  credit:
//    by David A. Mellis
//    modified 30 Aug 2011
//    by Tom Igoe
//////////////////////////////////////////////////////////////////////////////////////////////////////////////////////////////////////////////

//////////////////////////////////////////////////////////////////////////////////////////////////////////////////////////////////////////////
long MeasureDistance()
//////////////////////////////////////////////////////////////////////////////////////////////////////////////////////////////////////////////
{
  // establish variables for duration of the ping, 
  // and the distance result in inches and centimeters:
  long duration, inches, cm;

  // The PING))) is triggered by a HIGH pulse of 2 or more microseconds.
  // Give a short LOW pulse beforehand to ensure a clean HIGH pulse:
  pinMode(pingPin, OUTPUT);
  digitalWrite(pingPin, LOW);
  delayMicroseconds(2);
  digitalWrite(pingPin, HIGH);
  delayMicroseconds(5);
  digitalWrite(pingPin, LOW);

  // The same pin is used to read the signal from the PING))): a HIGH
  // pulse whose duration is the time (in microseconds) from the sending
  // of the ping to the reception of its echo off of an object.
  pinMode(pingPin, INPUT);
  duration = pulseIn(pingPin, HIGH);

  // convert the time into a distance
  inches = microsecondsToInches(duration);
  cm = microsecondsToCentimeters(duration);

  return inches;
}

//////////////////////////////////////////////////////////////////////////////////////////////////////////////////////////////////////////////
long microsecondsToInches(long microseconds)
//////////////////////////////////////////////////////////////////////////////////////////////////////////////////////////////////////////////
{
  // According to Parallax's datasheet for the PING))), there are
  // 73.746 microseconds per inch (i.e. sound travels at 1130 feet per
  // second).  This gives the distance travelled by the ping, outbound
  // and return, so we divide by 2 to get the distance of the obstacle.
  // See: http://www.parallax.com/dl/docs/prod/acc/28015-PING-v1.3.pdf
  return microseconds / 74 / 2;
}

//////////////////////////////////////////////////////////////////////////////////////////////////////////////////////////////////////////////
long microsecondsToCentimeters(long microseconds)
//////////////////////////////////////////////////////////////////////////////////////////////////////////////////////////////////////////////
{
  // The speed of sound is 340 m/s or 29 microseconds per centimeter.
  // The ping travels out and back, so to find the distance of the
  // object we take half of the distance travelled.
  return microseconds / 29 / 2;
}

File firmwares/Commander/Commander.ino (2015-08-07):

/*
  Commander.ino - default firmware for arbotiX Commander (V1.1)
  Copyright (c) 2009-2012 Michael E. Ferguson.  All right reserved.

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
*/


#define RIGHT_V   0
#define RIGHT_H   1
#define LEFT_V    2
#define LEFT_H    3

#define BUT_L6    13
#define BUT_L5    12
#define BUT_L4    11
#define BUT_LT    9

#define BUT_R3    7
#define BUT_R2    6
#define BUT_R1    5
#define BUT_RT    8

#define BUT_RIGHT 3
#define BUT_LEFT  2

#define USER      10

#define FRAME_LEN 33         // 30hz
unsigned long ltime;         // last time we sent data

int i;
void setup(){
    Serial.begin(38400);
    ltime = millis();
    pinMode(USER,OUTPUT);    // user LED
    
    // pullups for buttons
    digitalWrite(BUT_L6, HIGH);
    digitalWrite(BUT_L5, HIGH);
    digitalWrite(BUT_L4, HIGH);
    digitalWrite(BUT_LT, HIGH);
    digitalWrite(BUT_R3, HIGH);
    digitalWrite(BUT_R2, HIGH);
    digitalWrite(BUT_R1, HIGH);
    digitalWrite(BUT_RT, HIGH);
    
    digitalWrite(BUT_RIGHT, HIGH);
    digitalWrite(BUT_LEFT, HIGH);
    i = 0;
}

void loop(){
    int right_V = (1023-analogRead(RIGHT_V)-512)/5 + 128;
    int right_H = (analogRead(RIGHT_H)-512)/5 + 128;
    int left_V = (1023-analogRead(LEFT_V)-512)/5 + 128;
    int left_H = (analogRead(LEFT_H)-512)/5 + 128;
         
    char x = 'p';

    unsigned char buttons = 0;
    if(digitalRead(BUT_R1) == LOW) buttons += 1;
    if(digitalRead(BUT_R2) == LOW) buttons += 2;
    if(digitalRead(BUT_R3) == LOW) buttons += 4;
    if(digitalRead(BUT_L4) == LOW) buttons += 8;
    if(digitalRead(BUT_L5) == LOW) buttons += 16;
    if(digitalRead(BUT_L6) == LOW) buttons += 32;
    if(digitalRead(BUT_RT) == LOW) buttons += 64;
    if(digitalRead(BUT_LT) == LOW) buttons += 128;
   
    if ( left_V >= 200) {
     x = 'F'; 
    }    
    else if (left_V <= 100){
      x = 'T';     
    }
    else if ( left_H >= 150) {
     x = 'D'; 
    }
    else if (left_H <= 50){
      x = 'E';
    }
    else x = 'P';
    
    
    Serial.println(x);
   /* 
    Serial.println("rightV ");
    Serial.println((unsigned char) right_V);
    Serial.println("rightH ");
    Serial.println((unsigned char) right_H);
    Serial.println("leftV ");
    Serial.println((unsigned char) left_V);
    Serial.println("leftH ");
    Serial.println((unsigned char) left_H);  
    */
    //Serial.println("buttons ");
    //Serial.println(buttons);              // buttons
    //Serial.println((unsigned char)0);     // extra
    //Serial.println((unsigned char)(255 - (right_V+right_H+left_V+left_H+buttons)%256));
    
    
    if(i > 10){
      digitalWrite(10,HIGH-digitalRead(10));
      i=0;
    }
    i++;
    
    delay(FRAME_LEN);
//    delay(500);
}

/* Revisions 
 *  V1.2 - Feb 11, 2012 - Updated for Arduino 1.0
 *  V1.1 - Feb 19, 2010 - Replaced Walk/Look with Right/Left 
 *         (since apparently, I used something called "southpaw")
 *  V1.0 - Feb 10, 2010 - Firmware Finalized
 */

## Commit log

2015-04-09 arquivos usados no projeto
    [Bearing.scad, Bearing.stl, body_panel_top_without_hole.stl]
2016-08-22 static walk (arduino)
2018-08-24 renaming ros package dir. moving rofi calibration script

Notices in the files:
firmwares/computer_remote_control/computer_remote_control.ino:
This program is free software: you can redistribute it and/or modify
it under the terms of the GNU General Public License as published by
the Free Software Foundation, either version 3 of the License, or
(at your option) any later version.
